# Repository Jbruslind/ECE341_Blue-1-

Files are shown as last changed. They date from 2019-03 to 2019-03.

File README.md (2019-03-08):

# ECE341 Final Project - AC Bluetooth Switch
Final project for ECE 341 (Junior Design II). Made by Jorian Bruslind, Mack Hall, and Zach Bendt. 
This project uses an ESP32 microcontroller to facilitate all the necessary functions: Relay control, 
sensor measurement, relay control, and bluetooth/wifi connections. 
#	Requirements for project

##	Base Engineering requirements
The project's base requirements, standard for all bluetooth switch teams

1. The system will turn off and on at least 2 independent household lamps with up to 100W incandescent 
bulbs and report current watts delivered by each channel.
2. 9 out of 10 users will be able to turn the switches off and on from a mobile phone in less 
than 10 seconds without any training or having previously seen the interface.
3. The system will use only US standard plugins for connecting to external devices and will not 
allow any object with a diameter greater than 1mm to enter the enclosure, and will be disable if 
more than 5A is drawn from the wall power.
4. The system must turn off the output after a time of up to 1 hour ± 1 minute when enabled.
5. The system will be able to accept commands from a mobile phone over 20 feet away from the plug-ins.

##	Specialized requirements
The project also allowed for teams to specify their own 2 unique requirements

1. The system will have WiFi capabilities 10m or more away from a standard household router and 
will have a web interface that is accessible from a laptop/browser. 
2. The system must be able to accept voice commands through a mobile phone using the Google Now 
API for all functionality. 

# System Overview
The overall project was broken up into many different "blocks" that could be individually assigned
and constructed. 

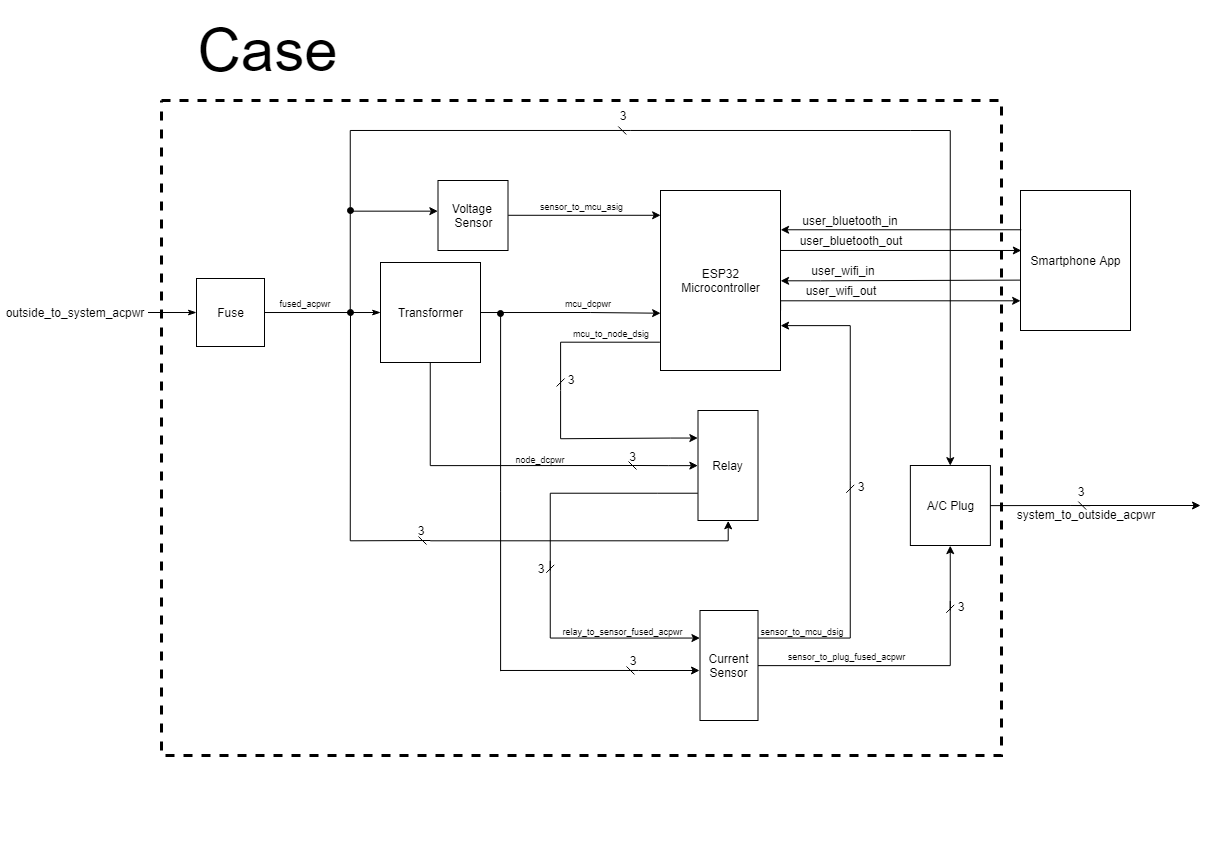
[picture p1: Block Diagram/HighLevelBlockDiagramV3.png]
Block Diagram connections


1. Fuse - Find a fuse (or circuit equivalent) that is able to break only at 5A within ~.5sec. 
This should be resettable and can be inserted easily into a PCB

2. Transformer - This block is supposed to take in 120Vac (US mains power) and convert it
down to 5V at ~2A. 

3. Voltage Sensor - This block will measure 120Vac and output some measurable signal. 
This could be a radiometric voltage (0-5V) or through some serial protocol.

4. Relay - This block should be a electrically controlled switch (a relay), that can 
take in some voltage signal from 0 - 5V and switch a voltage line which will be 120Vac @ 0 - 5A

5. Current Sensor - This block will take in the individual 120Vac lines (3 total)
and output a signal that corresponds to the current flowing through said lines. This
signal can be radiometric or serial.

6. AC plug - This block will output the shared 120Vac line (after it goes through each relay)
and have accessible ports to 120Vac (line), 0V (neutral), and earth ground. 

7. Smartphone app - This will be a piece of software that can be run on a typical
android OS version (4.0+) and can interface with the ESP32 controller. It must be
"user friendly" in that someone with no exposure to the device prior will be able
to navigate it. This must also use the Google Now API for voice activation/control

8. Wifi Control (not pictured) - This must be some piece of software that allows
for control of the ESP32 microcontroller through a "user friendly" interface. There
are little restrictions to how this can be done other than it must use Wifi and be 
easy to navigate. 

# More info

Each directory has a small readme file that explains what aspect it served in the project
as well as more information about how the project was done. (Example: PCB production files
contain info about the PCB)

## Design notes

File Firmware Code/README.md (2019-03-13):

# Firmware Code

This folder holds all of the code used throughout this project. This code is primarily used for 
controlling the microcontroller used on the custom PCB, the ESP32. The code was done in C++ via 
the Arduino IDE. Within the folder, there also exists the flow diagram for the NodeRed server 
that handles the user web interface.

Individual pieces of code are present in this folder, which was how they were developed. After the
individual pieces of code were able to successfully work on their own, they were adapted into a
single .ino file to be uploaded to the ESP32, called ESP_Firmware.

##	Functions

###	void check_time()
Helper function whose main job is to check the timers and current time. When the current time 
minus the time each timer started goes beyond the set time limit, it calls a separate function 
to turn off the plugs and reset all the values. 

This could be improved by consolidating the functions (a previous revision needed 3 seperate functions
this current revision does not) so only one "timer complete" function is called with a specific argument 
for what plug to turn off (Ex. Timer_complete(1) -> turn off plug one). 

Inputs: None

Outputs: none

### String get_time(int time_to, int plug)

Helper function that will convert the time data variables (which are stored as raw millisecond values) to
human-readable strings. In this case it will take in the time at which the plug timer started (time_to) and
how long the plug is supposed to remain on (plug). These values are used along with the current time (millis)
to find exactly how long it's been since the plug timer started. This value is then divided into hours, minutes
and seconds and then casted into a string with the format HH:MM:SS. 

This function is kinda clunky because it uses strings and not char arrays. Since the format is known (HH:MM:SS) 
it would be better to just have a 8 char static array and then populate it with values as we calculate them. 

Inputs: Time that the timer started at (time_to), how long the timer is on for (plug)

Outputs: String formatted as HH:MM:SS (int values)

### void timer_complete_X()

There are 3 of these functions for each plug. All it does is turn "off" the plug (by setting the relay high) and
resets the time the plug is supposed to be on to 0. 

This is kind of a stupid way to do this and it should definitely be improved. Consolidating it into another function
and not having 3 seperate functions to do a very simple task would be a good start. 

Inputs: None

Outputs: None

###	setup_wifi()

This function will attempt to connect to the specified wifi SSID with the given password. IT is a blocking function 
and will hold up all other operations if it cannot connect to the givien SSID. 

This should be fixed so that it is not blocking and will just retry the connection every X seconds when it can't connect.

Inputs: None

Outputs: None

###	 start_timers()

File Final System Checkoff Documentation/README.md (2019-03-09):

# Final System Checkoff Documentation

This folder holds all of the artifacts used to demonstrate to our client, Westley Wurscher, that our system has met all of the engineeering requirements that we had agreed upon. All of the PDFs are artifacts showing a rough idea of how our system works, including a block diagram, interface definitions, a BOM, and more. 

There is also a folder called "Videos", which has (you guessed it) videos that show our system working as intended. We have a video to show that our timer is capable of reaching 60 minutes and capable of keeping time, a video showing that our system turns off once our timer is finished, a video showing that the system is controllable via bluetooth smartphone app, a video showing that our system is controllable through a WiFi interface, and, finally, a video showing that our system is controllable via a voice command input.

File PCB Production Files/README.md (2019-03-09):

# PCB Production Files

This directory holds all the necessary information/files to manufacture the project
PCB. The manufacturing files directory holds all the gerber files (7 layers: Top Copper Layer, 
Top Silkscreen Overlay, Top Soldermask Layer, Bottom Copper Layer, Bottom Silkscreen 
Overlay, Bottom Soldermask Layer, and the Keepout Layer which serves as the board outline).
This directory also holes the drill files (Slotted holes and round holes)

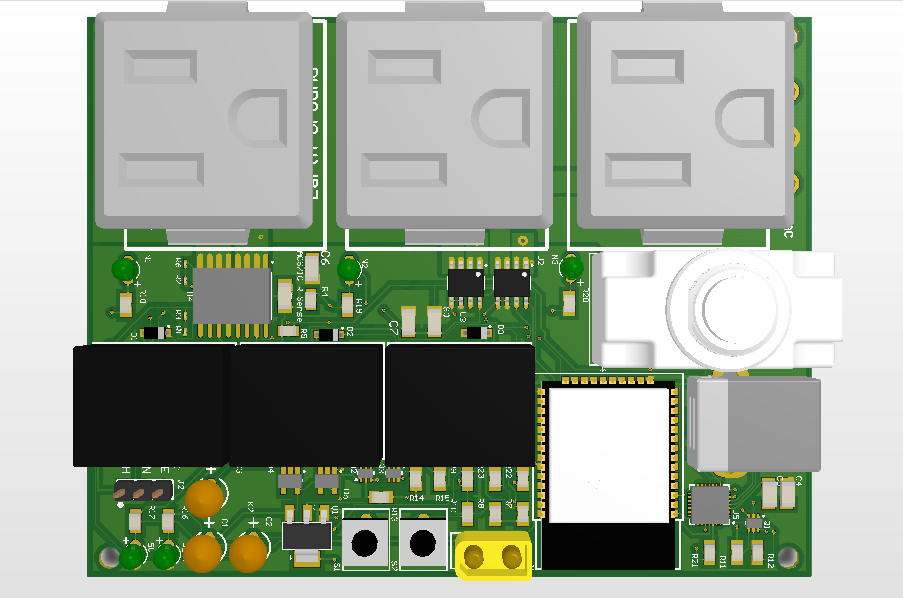
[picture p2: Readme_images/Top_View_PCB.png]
Render of board


The gerber files directory contains all the above files as well as all the other layers
that are not used in production (usually just used for reference inside CircuitMaker). This
includes some layers which we used to designate spacings between objects and layers used
to create unqiue shapes of copper pours. 

The Bluetooth Switch directory holds all specific information about the project which
include pdf versions of all schematics and the PCB print, as well as other useful files 
such as a Bill of Materials and STEP file output of the whole board. 

## Special Layout Considerations

There weren't very many layout considerations that had to be made for this project. 
Other than trace sizes and component placement, the only special considerations that had
to be made involved the placement of the I2C signal lines, placement of the UART D+ and D-
lines from the UART-TTL bridge and the spacings between the AC voltage lines and the DC 
signal/power lines. The PCB was grouped into various segments to simplify component placement.
For example, the ESP32 segment included the ESP32, USB programmer, UART Bridge, EN/Boot
transistor and peripheral capacitors/resistors. This was grouped this way so all the 
important connections would be close together for easy routing. Other groupings
included the relay nodes (which included the relays, current sensors, flyback diodes, 
status LEDs, output plugs, and peripheral resistors/capacitors) and the power supply
which included the ORing diodes, input filtering capacitors, and Linear Dropout Regulator. 

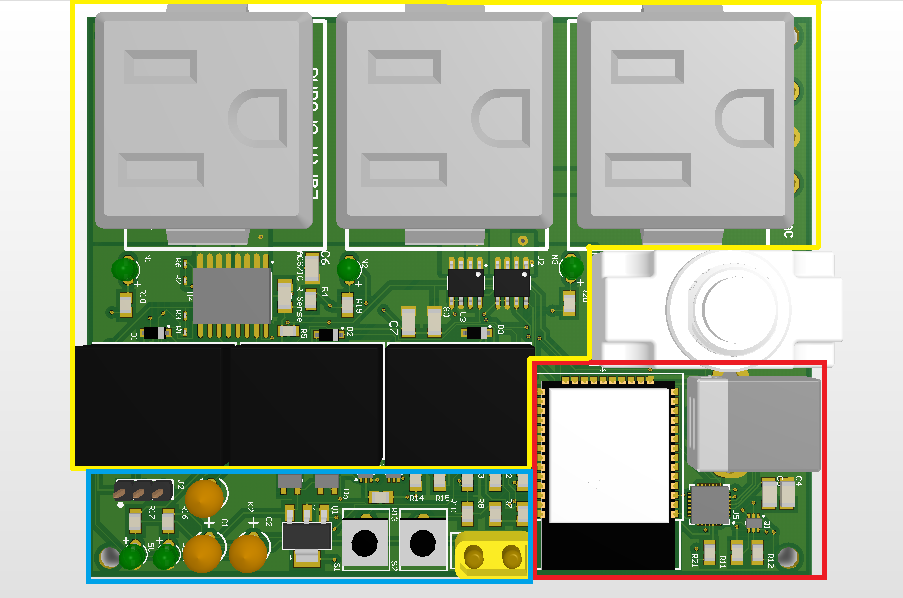
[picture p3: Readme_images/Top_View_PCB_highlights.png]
Highlighted Sections


1. Red indicates the ESP32 section
2. Blue indicates the Power section
3. Yellow indicates the Relay Node section

### Connectors
For this project, a USB B connection was chosen to act as our USB interface as it is 
robust and very durable. Initially the project used a USB micro due to its abundance
in other products, but this was found to be easily broken and torn out of the board. 

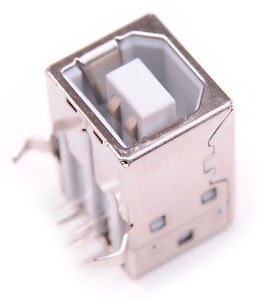
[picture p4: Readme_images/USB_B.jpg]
USB B Connector


The power outlets were chosen to be NEMA standard C13 plugs so that way we would only 
need to solder the plugs into the board (no wires). Unfortunatly most of these plugs
were panel mount, meaning it was not easy to plug into a PCB, but we were able to find 
PCB mount plugs (which were adapted panel mount plugs) on Digikey [here](https://www.digikey.com/product-detail/en/qualtek/739W-X2-32-A/Q1211-ND/8681866)

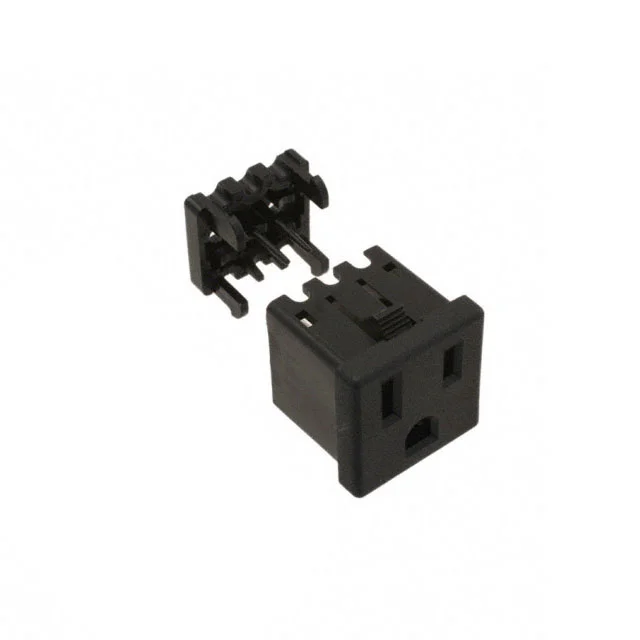
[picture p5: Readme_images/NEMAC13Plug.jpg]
C13 Plug made by Qualtek


The input DC power was chosen to be an XT30 plug which is a 2 pin, yellow, friction fit 
plug that is often used on drones/quadcopters for lithium batteries. DC power only needed
to provide .5A and the XT30 is rated for 30A per plug.  

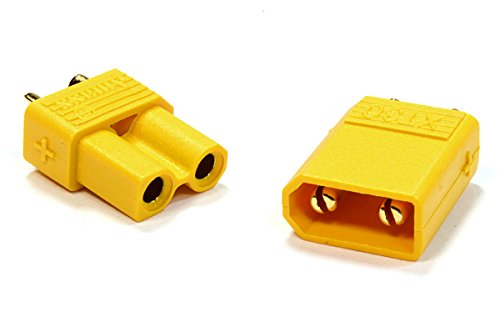
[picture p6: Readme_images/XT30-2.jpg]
XT30 Connectors


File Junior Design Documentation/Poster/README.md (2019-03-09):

# Poster

This project was for ECE 341/2 at Oregon State University. At the end of the second term, teams would show off their projects at a Junior Design Expo. This was the poster used to show off this project on 3/14/19 by Bluetooth Switch group 1.

This folder contains all of the artifacts and pictures used to decorate the poster. These include mechanical drawings of the case, a rendering of the populated PCB, a block diagram of the entire system, a graph showcasing the sampling technique used to calculate RMS values, and a picture of the user interface for both the smartphone app and web interface respectively.

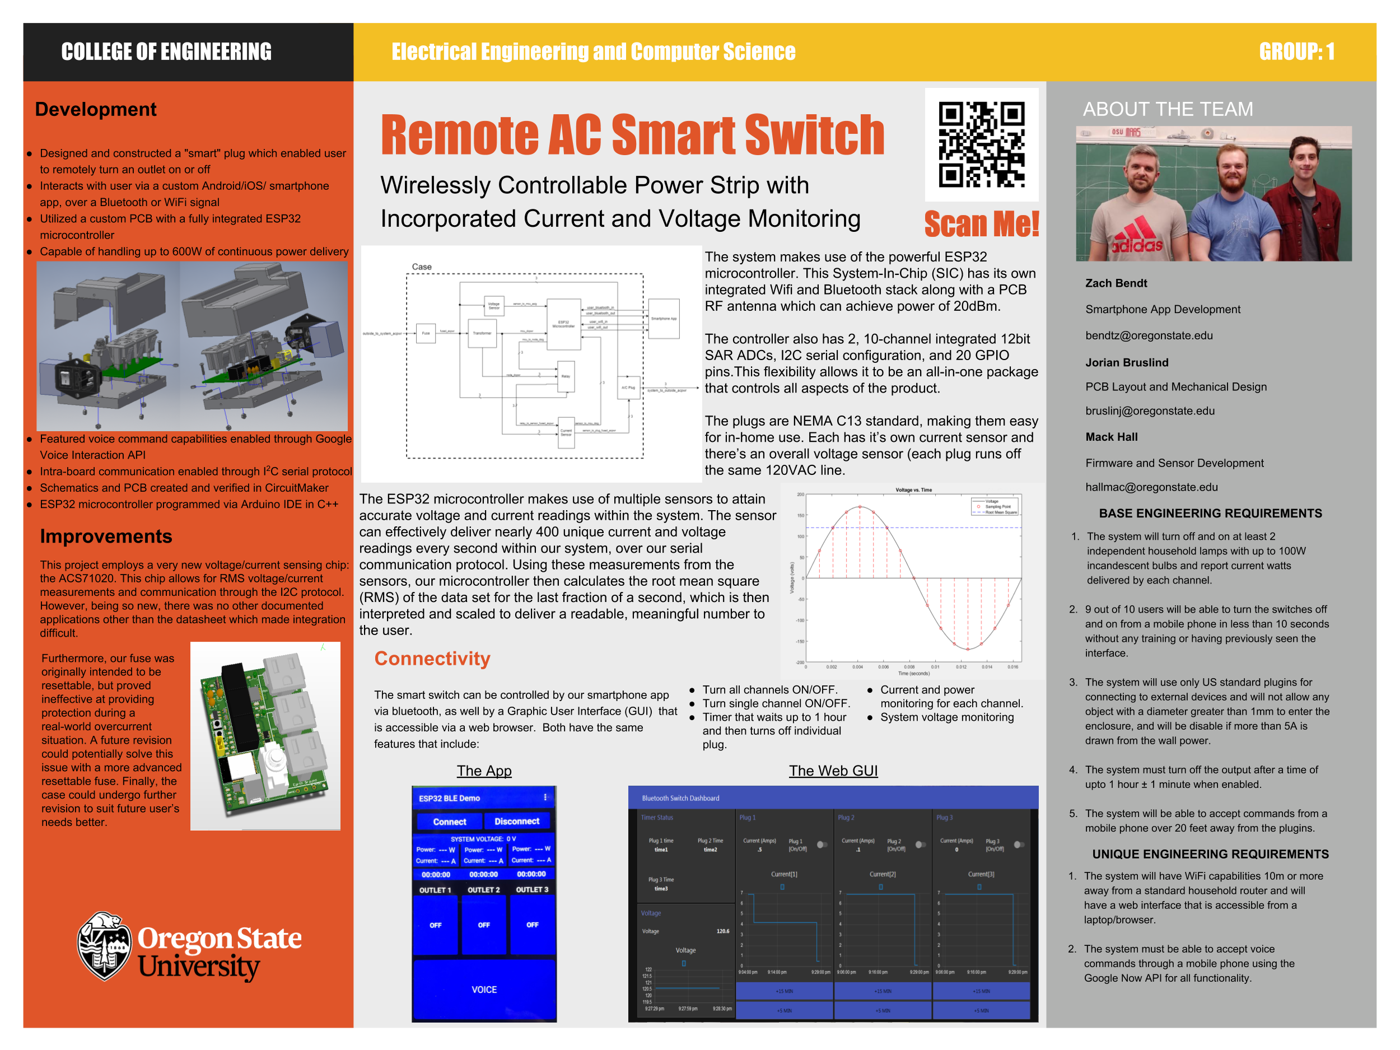
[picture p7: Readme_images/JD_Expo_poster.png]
Poster


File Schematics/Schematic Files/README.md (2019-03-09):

#	Schematic files
This folder contains all the schematic files as pdfs for easy viewing. The project
was designed using the Altium Circuitmaker software. All project files are open 
for anyone to use and can be found in the project search engine within Circuitmaker. 
##	MCU
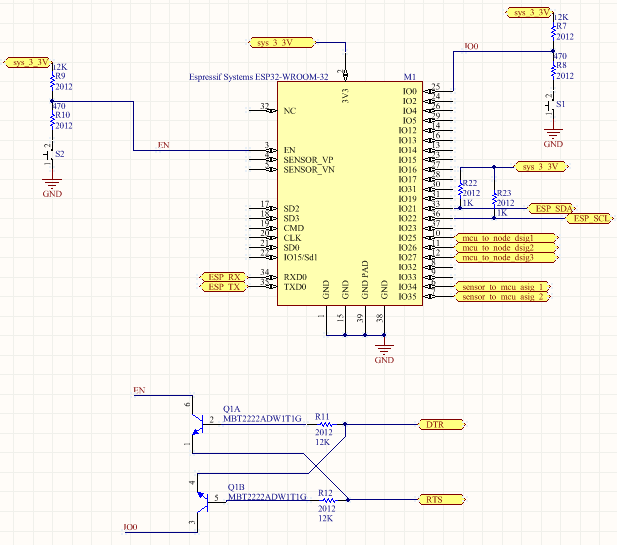
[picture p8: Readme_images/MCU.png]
MCU


This is the ESP32 general connection page which provides ports to the other 
necessary sheets within the project. The ESP needs a 3.3V VDD and all its pins
are 3.3V tolerant (not 5V). The inputs are for the I2C bus, 2 radiometric current sensors, 
3 relay control lines, UART programming, and for power/gnd.

The BJTs are used for programming the ESP over USB (seen below in the UART->TTL bridge).
The switches on EN and IO0 are used for programming and resetting respectively.

##	UART Bridge
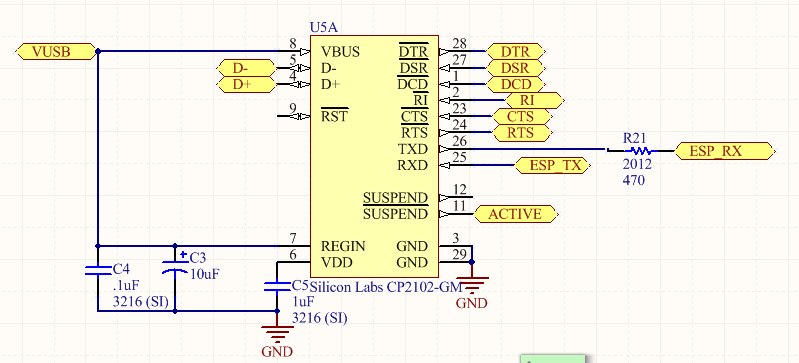
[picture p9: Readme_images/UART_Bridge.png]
UART Bridge

 
 The ESP32 does not have a native way to communicate over UART (USB signals), so a UART-TTL bridge
 was chosen to perform that job. The Silabs CP2012 is a popular choice among other microcontroller
 development boards and has a proven design. This chip will take in the USB signals from some external
 controller and program the ESP32. 
 
 ##	3.3V LDO
 
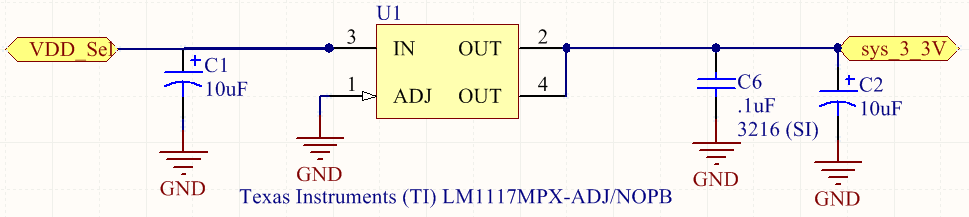
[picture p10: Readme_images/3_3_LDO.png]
3.3V LDO
 
 
 The input voltage that we are using for this board is expected to be 4.5 - 5.5V. The ESP32 and 
 the other peripheral sensors cannot tolerate this voltage normally. So a Low Dropout Regulator
 was chosen to step this 5V voltage down to 3.3V. This was chosen to be the LM1117 which is, again,
 a popular choice among development boards for 3.3V supplies. The necessary current was calculated
 to be ~.5A for all the board components (.3A alone for the relays). The LM1117 can supply up to .8A
 at max, which was more then enough for our application. 
 
 ##	Input Plugs
 
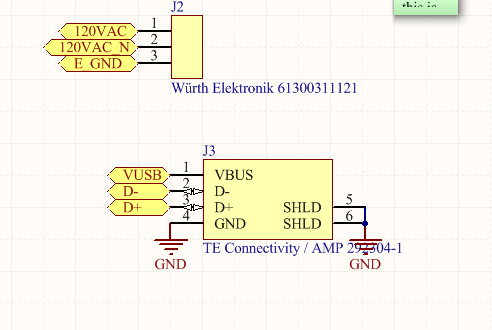
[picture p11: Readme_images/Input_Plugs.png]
Input Plugs
 
 
 This schematic is just the input USB port (for programming/power of the ESP32 and sensors)
 as well as testing pins for the 120Vac (line, neutral, and Egnd). 
 
 ## Current Sensor ACS722
 
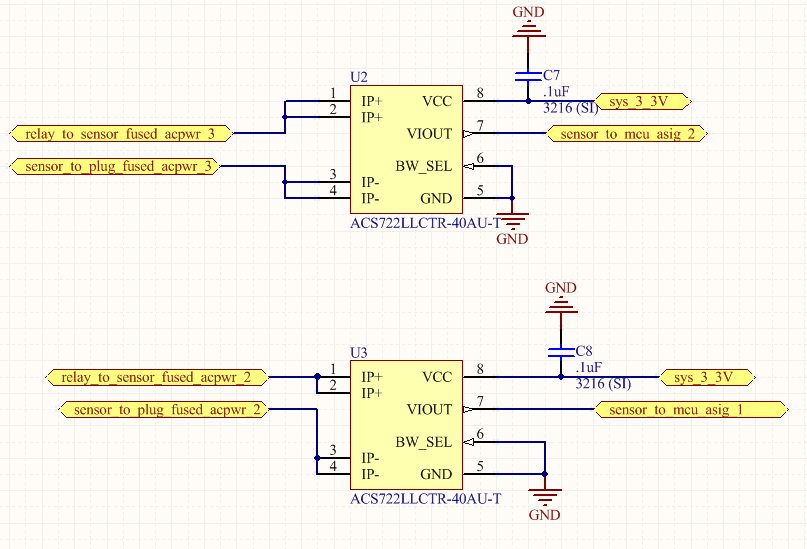
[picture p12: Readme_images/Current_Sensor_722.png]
ACS722 Current Sensor
 
 
 The ACS722 is a very powerful current measuring chip that uses the Allegro Hall effect technology. This 
 chip is able to measure up to +-10A of current and output the result as a radiometric voltage signal
from 1.5V -> 0A to 3.3V -> 10A. This is a linear relationship and has a sensitivity of ~267mV/A. 
Using the ESP32's built in Analog - Digital Converters (ADCs) we are able to measure this signal 
with an accuracy of 12 bits over 3.3V (as in 0000.... = 0V and 1111.... = 3.3V) with a resolution
of 2^12 / 3.3V (or ~.8mV). This translates to a  .8mV/bit * 1/267 A/mV = .003 A/bit or 3mA resolution.

## ACS71020 

ACS71020 Current/Voltage Sensor

This chip is actually a very powerful current/voltage sensor for AC applications. Not only is it able to tolerate 120Vac up to
30A, it can also preform RMS, power, actual power, and instantaneous power. The package is also isolated
for voltages up to 1047Vrms in basic isolation and 517Vrms in reinforced isolation. The measurement values
are read over the I2C bus, making communication easy and space efficient. 

*note*: we actually had a very difficult time getting this part to work as the chip itself is very new
(released around Nov '18) and no examples for implementation were found online. So we had to make our 
own I2C drivers for this, which proved difficult as we were inexperienced. 

## Relay Node

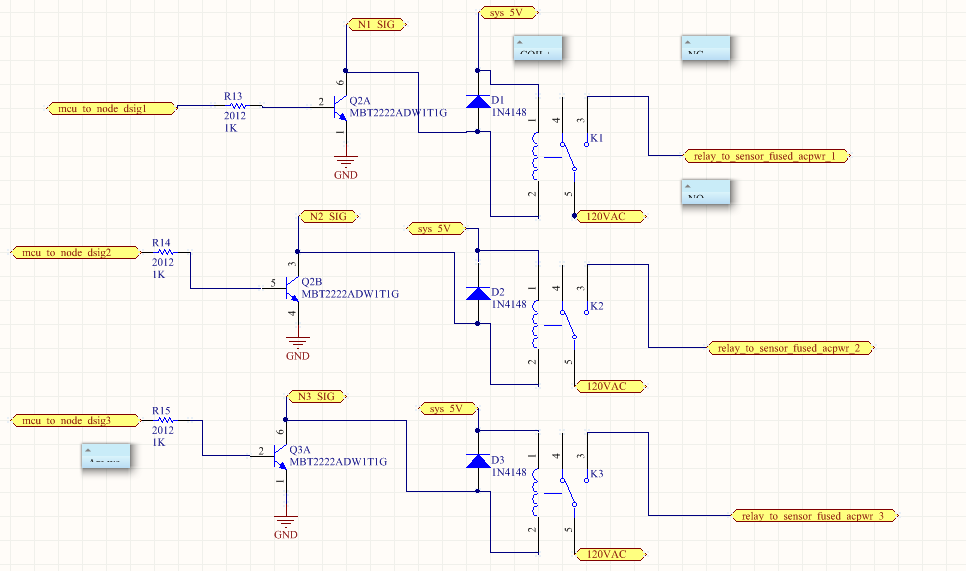
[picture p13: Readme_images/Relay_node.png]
Relay Node


For this the relays are simply electromechanical with a rated usage of ~100,000 switches. They are 
5V compatible and take ~70.2mA for full activation/saturation. In this circuit the ESP will send a 
3.3V signal to a 2N222 bjt amplifier (with ~100 gain, this equates to ~.7mA from the ESP) which in
turn will supply the necessary current for the relays. Each one has an LED line attached to it so that
there will be a status LED which will light up when active (when the ESP sends a +3.3V signal). As of 
the writing of this, the relays were connected wrong in that the output line was connected to the 
"Normally Closed" (NC) pin of the relay (meaning when ESP sends 3.3V it will be open, and normally closed)
This should be changed to the "Normally Open" pin. 

## Voltage Selection Diodes

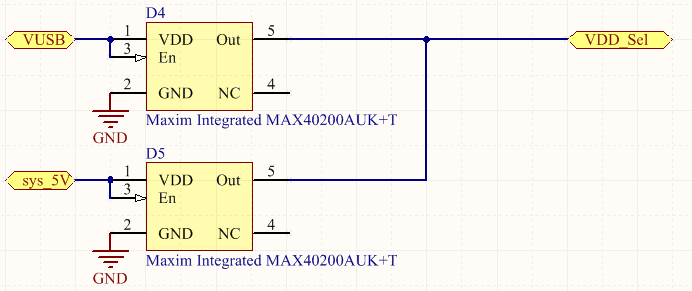
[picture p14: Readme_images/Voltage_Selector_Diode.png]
Voltage Select


There will be situations where we would like to only power the ESP32/peripheral sensors (to program, test, etc) and *not* 
anything else (since powering the relays might overcurrent a USB 2.0 port on say a laptop. As such it would be good to have 
a USB voltage input and a normal 5V input. Having 2 separate voltages however can cause issues (if they are trying to 
backdrive each other). A solution was made where we would use 2 Oring diodes that will only let the higher of the 2 
voltages act as the driving voltage, while still allowing the other to be connected. This lets us power only the 
ESP32/periphery using the USB voltage (to program) and still being able to plug in the 5V line later on if we want to 
do testing. We can also power the whole board from the main 5V while using the USB connection 
to do debugging.

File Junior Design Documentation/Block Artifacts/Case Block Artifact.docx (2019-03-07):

Jorian Bruslind

2/7/19

ECE 342 - Blue 1 | AC Bluetooth Switch

Prof. Shuman

Interface & Property Definition Table for AC Bluetooth Switch Case

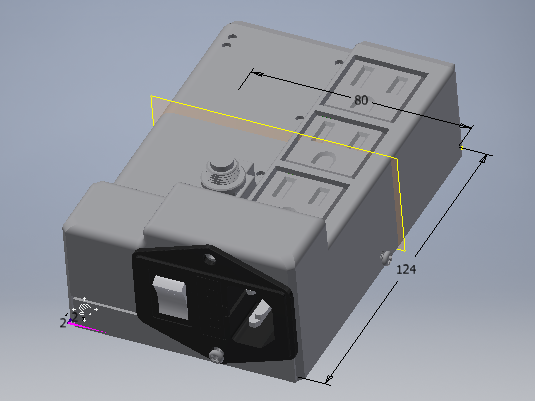
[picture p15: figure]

Fig. 1. Render of Case

This is our enclosure for our AC Bluetooth switch. It is fully 3D printed using PLA plastic, which will have a total print time of roughly 12 hours. The goal for this case was to ‘ruggedly’ enclose the system, which has been specified as not allowing anything bigger than a pencil be able to pass through. Furthermore, all wire connections to the PCB going through the enclosure (entering or leaving) must use connectors.

The case exposes a NEMA-15R compliant input plug to receive power from the wall, a physical on/off switch, and three output channels to plug NEMA-15R components into that you wish to power. Every other component of the project is enclosed by the 124mm x 80mm x 50mm case. The custom PCB is held on four standoffs, while the top of the case is mated to the bottom via four M3 screws.

Table 1. Interface Definitions

outside_to_system_acpwr | NEMA-15R compliant VNominal: 120VACRMS VMin: 0V Physical cutoff switch
system_to_outside_acpwr | NEMA-15R compliant VNominal: 120VACRMS * 3 channels VMin: 0V * 3 channels


Fig. 2. High Level Block Diagram of System

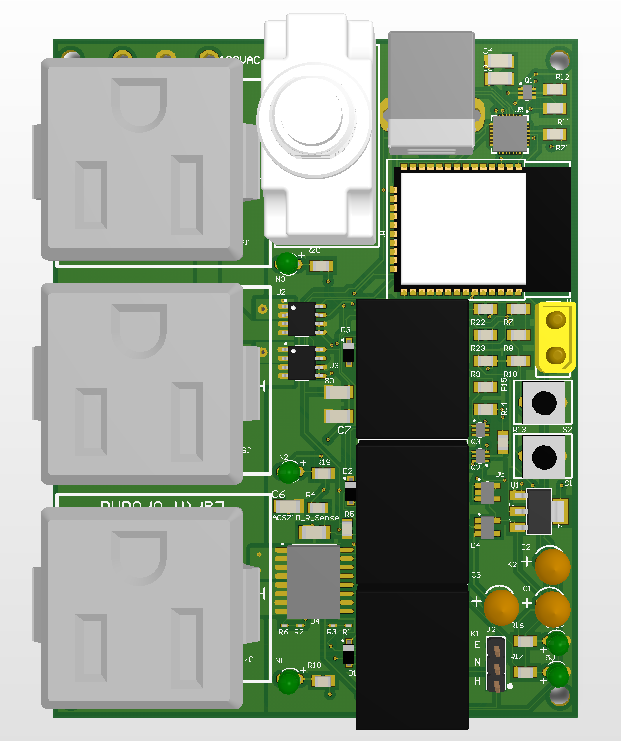
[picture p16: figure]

Fig. 3. Render of the PCB to be enclosed

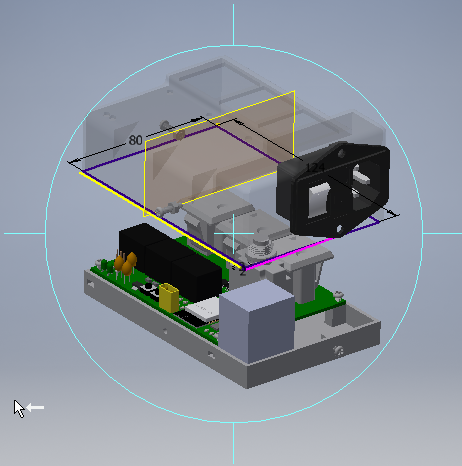
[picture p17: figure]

Fig. 4. Isometric Exploded View of the Case

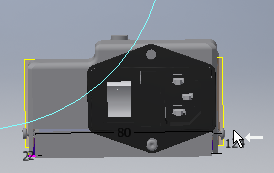
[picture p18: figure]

Fig. 5. Side View of the Case

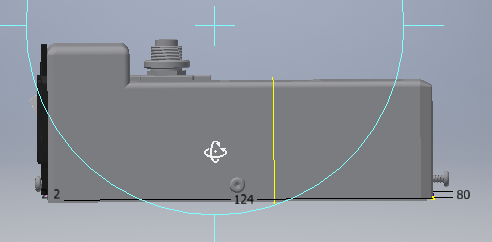
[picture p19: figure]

Fig. 6. Rotated Side View of the Case

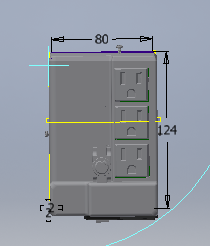
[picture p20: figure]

Fig. 7. Top View of the Case

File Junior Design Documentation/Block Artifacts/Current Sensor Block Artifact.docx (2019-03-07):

Mack Hall

2/7/19

ECE 342 - Blue 1 | AC Bluetooth Switch

Prof. Shuman

Interface & Property Definition Table for ACS722LLCTR-40AU-1 Current Sensor

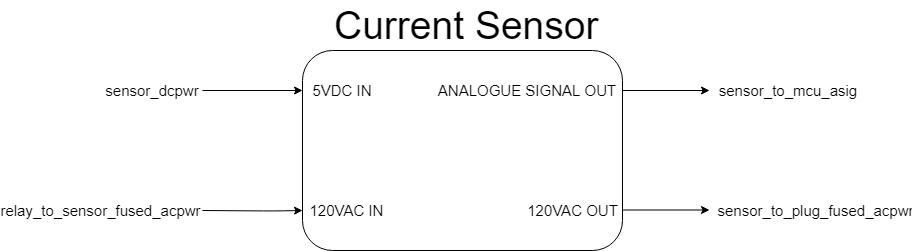
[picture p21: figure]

Fig. 1. Black Box Diagram of Current Sensor Block

Table 1. Current Sensor Block Interfaces and Properties

Interface | Properties
sensor_dcpwr | VMin: 3VDC VNominal: 3.3VDC: VMax: 3.6VDC INominal: 9mA IMax: 12mA
sensor_to_mcu_asig | VMax: 6 VDC VNominalLow: 0.36 VDC VNominalHigh: 5 VDC VMin: -0.5 VDC tRise: 4㎲ tResponse : 5㎲ tProp: 1㎲
relay_to_sensor_fused_acpwr | VNominal: 120VACRMS IMax: 5A IMin: -5A fNominal: 60Hz
sensor_to_plug_fused_acpwr | VNominal: 120VACRMS IMin: -5A IMax: 5A fNominal: 60Hz

Fig. 2. High Level Block Diagram of AC Bluetooth Switch


Fig. 3. Schematic for Current Sensor Connections

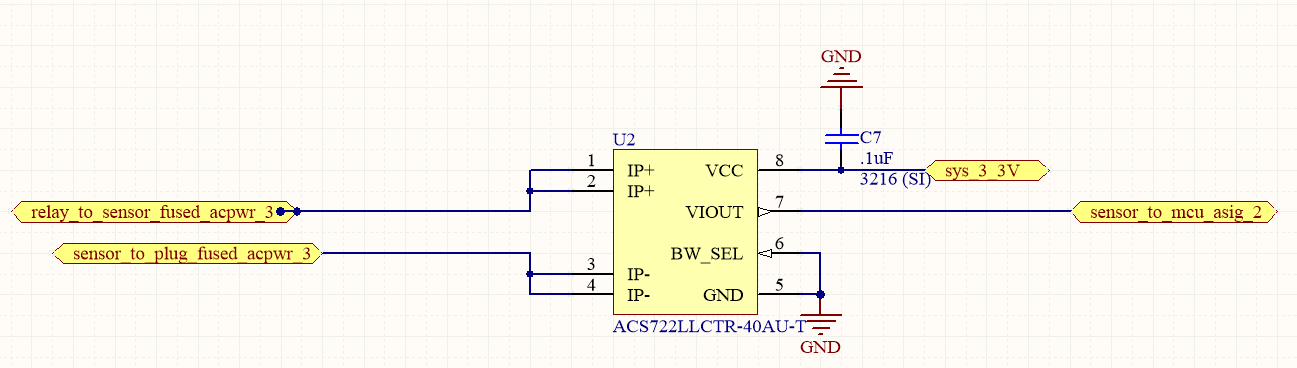
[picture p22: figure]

Fig. 4. A Render of the PCB

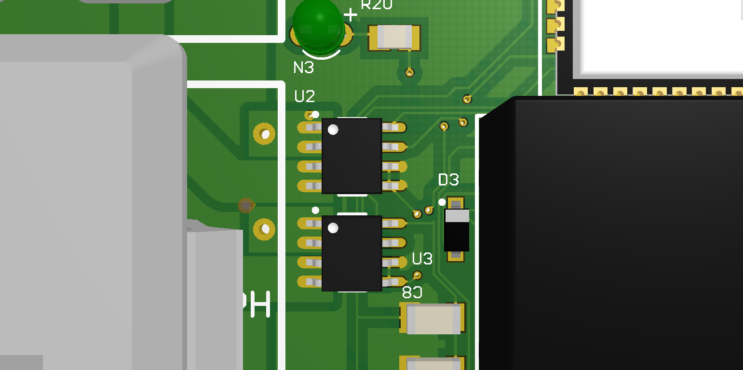
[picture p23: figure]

Fig. 5. Closeup of Current Sensor on PCB

Test Cases:

Nominal Current:

1. Connect the GND pin and the bit select pin to ground.
2. Apply 3.3 VDC to the VCC pin.
3. Connect the VIOUT pin to an ADC pin of a microcontoller. Take note of the reading it reports when there is no load attached. This is the zero-load bias we need to account for when taking later measurements.
4. Apply a load of 5A to the IP+ and IP- pins of the IC.
5. Subtract the zero-load bias we found earlier from the reported value. Afterwards, scale the result by the amount specified in the datasheet.

PASS: 5A +- 2% is being reported.

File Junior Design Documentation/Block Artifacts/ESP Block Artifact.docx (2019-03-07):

Mack Hall

1/25/19

ECE 342 - Blue 1 | AC Bluetooth Switch

Prof. Shuman

Interface & Property Definition Table

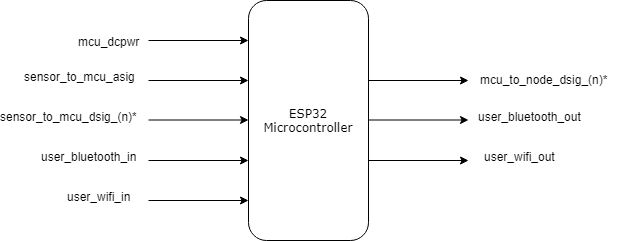
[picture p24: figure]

Fig. 1. Black Box Diagram of ESP32 Microcontroller Block

Table 1. ESP32 Microcontroller Block Interfaces and Properties

Interface | Properties
mcu_dcpwr | VNominal: 3.3VDC: VMax: 3.6VDC VMin: 2.3VDC IMin: 500 mA
sensor_to_mcu_asig | VMax: 6 VDC VNominalLow: 0.36 VDC VNominalHigh: 5 VDC VMin: -0.5 VDC
sensor_to_mcu_dsig_(n)* | VHighMin: 0.75*mcu_dcpwr VDC VHighMax: VDD + 0.3 VDC VLowMin: -0.3 VDC VLowMax: 0.25*mcu_dcpwr VDC
user_bluetooth_in | Must be able to enable/disable relays Must be able to set a time up to 60 min. Must be able to give commands from over 20 ft Interface must be via a mobile phone (Android)
user_wifi_in | Must be able to enable/disable relays Must be able to set a time up to 60 min. Must be able to give commands from over 20 ft Interface must be via a mobile phone (Android)
mcu_to_node_dsig_(n)* | Disables output after 1 hr. if timer enabled Operates output channels independently IMax: 1.2A IMin: 0A
user_bluetooth_out | Must be able to report on current/voltage draw Must be able to report data to phone 20 ft away Must be able to confirm length of timers Must be able to disable channels if timer is up
user_wifi_out | Must be able to report on current/voltage draw Must be able to report data to phone 20 ft away Must be able to confirm length of timers Must be able to disable channels if timer is up

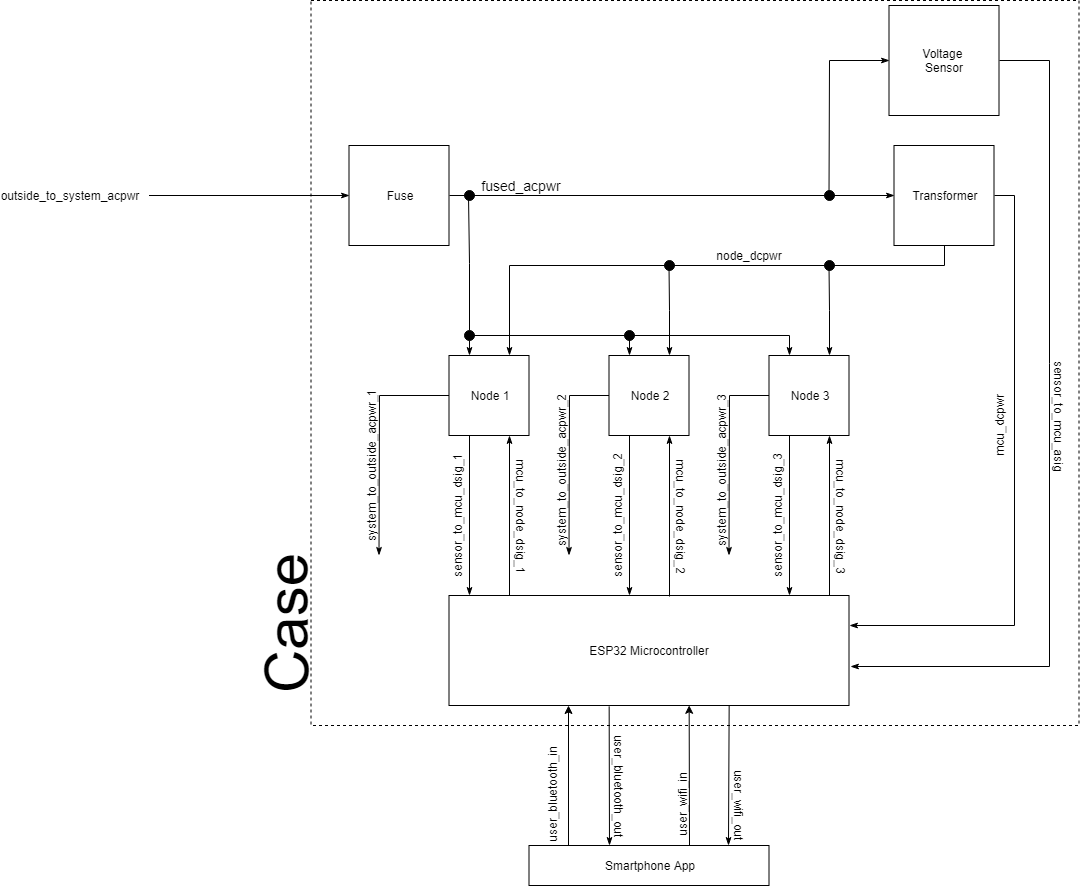
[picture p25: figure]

Fig. 2. High Level Box Diagram of AC Bluetooth Switch


Fig. 3. Schematic of ESP32 Microcontroller Block in Custom PCB

Fig. 4. Schematic of Custom PCBFig. 5. Closeup of Schematic of ESP32 Microcontroller Slot on Custom PCB


NOTE: The KEEPOUT section has no traces running through it, as to avoid interference with the bluetooth and WiFi signals the microcontroller is sending and receiving.

Fig. 6. Custom Code written to the ESP32 Microcontroller

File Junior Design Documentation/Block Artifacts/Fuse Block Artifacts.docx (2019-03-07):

Zachary Bendt

January 17, 2019

Remote A/C Switch

Team Blue(1)

Fuse Block Artifacts

Interface | Properties
outside_to_sytem_acpwr | - Vnominal: 120VAC via a NEMA 5-15R connector - Ipeak: 15A - Inominal: 500mA
fused_acpwr | - Vnominal: 120VAC via a NEMA 5-15R connector - Ipeak: 4.5A - Inominal: 500mA - Disconnects system from input when 5A draw is exceeded

Testing

It is assumed that peak current, nominal voltage and current are within requirements as they are supplied by wall outlet.

Steps

A. Disconnects system from input when 3A draw is exceeded

The block should disconnect from the system when the 4.5A limit is reached in order to protect the system from overcurrent. This will test if the fuse is functioning property.

1. Connect the Fuse to a power supply via the outside_to_sytem_acpwr interface at 5V.

2. Connect the Fuse to the DC load at the fused_acpwr interface.

3. Starting with a 100 mA load, slowly increase the load until the 4.5A limit is exceeded.

PASS: Disconnects system from input when 4.5A draw is exceeded.

If the block passes all of the listed tests, all interface properties have been verified and the block is ready for inclusion into the system.

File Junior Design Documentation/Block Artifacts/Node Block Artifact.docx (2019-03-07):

Node

node_dc_pwr

mcu_to_node_dsig

fused_acpwr

sensor_to_node_asig

system_to_outside_acpwr

Interface | Properties
node_dc_pwr | INominal : 261mA Imax : 296mA Vmax : 5.5V Vmin : 4.5V
fused_acpwr | INominal : 0 - 3A (depends on what’s plugged in) Imax : 5A Vmax : 125VAC Vmin : 115VAC
sensor_to_node_asig | INominal : <1mA Imax : <1mA Vmax : 3.3V Vmin : 0V
system_to_outside_acpwr | INominal : 0 - 3A (depends on what’s plugged in) Imax : 5A Vmax : 125VAC Vmin : 115VAC
mcu_to_node_dsig | INominal : 9mA Imax : 10mA Vmax : 3.3V Vmin : 0V

Testing Plan

This block has the relay and current sensor functions built into one. It must be able to switch 120VAC (fused_acpwr to system_to_outside_acpwr) over 0 - 5A using a standard 3.3V (mcu_to_node_dsig) signal from the ESP32. This block will also send information about the magnitude of current being passed to the system_to_outside_acpwr net through a standard 3.3V signal line (sensor_to_node_asig).

Relay Functionality

1. Start with everything powered off/de-energized.
2. Apply 5V to the node_dc_pwr line
3. Apply 3.3V to the mcu_to_node_dsig line
4. Visually confirm the status LED is active
5. Audibly confirm the relay is active (listen for the switch)
6. Using a multimeter in continuity mode, check that the relay terminals from NO to COM are connected.
7. Using a multimeter in ammeter mode, check the current flowing from mcu_to_node_dsig is less than 10mA
8. Repeat steps 3 - 7 for all other relays (if more than 1)

AC Power Functionality

1. Apply Relay Functionality steps 1 - 3
2. Using 120VAC standard household power lines, apply to fused_acpwr
3. While relay is active, measure voltage on COM (fused_acpwr) and NO (system_to_outside_acpwr) relay pins to confirm 120VAC (and that the relay is active)
4. De-energize AC circuit and place a multimeter in ammeter mode in series with the Hot line of the AC power
5. Energize the circuit with AC power
6. Slowly apply a load to the AC power lines until 5A is being drawn
7. Confirm relay is still active after 5A of current

Sensor Functionality

1. Apply Relay Functionality steps 1 - 3
2. Apply AC power steps 5 - 7
3. While ramping up current draw, measure voltage on sensor_to_node_asig and confirm up to 3.3V max (and linear scaling)
4. De-energize circuit and put ammeter in series with sensor_to_node_asig
5. Apply steps 1 - 2 and confirm current draw does not exceed 1mA on sensor_to_node_asig

Node Power functionality

1. Put ammeter in series with node_dc_pwr
2. Apply Relay functionality steps 1 - 3
3. Measure current draw and confirm it is not over 296mA

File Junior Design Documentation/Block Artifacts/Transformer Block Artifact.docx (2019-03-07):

Block 2 Checkoff

Transformer

Transformer Block Introduction

The transformer block includes the transformer which steps down the 120VAC to 5VDC as well as the voltage regulator that converts the 5V to 3.3V. The transformer was salvaged from a Vogek ST270 USB Wall Charger, shown in Figure 1. We removed the USB connectors and connected the transformer to our PCB using an XT30 connector, shown in Figure 4.


Figure 1. Vogek ST270 USB Charger

Block Diagram

Transformer

fused_acpwr

mcu_dcpwr

node_dcpwr (n)

Figure 2. Block diagram for Transformer Block

Interface Definitions

Interface | Properties
fused_acpwr | INominal : 0 - 3A (depends on what’s plugged in) Imax : 5A Vmax : 125VAC Vmin : 115VAC
mcu_dcpwr | INominal : 100mA Imax : 125mA Vmax : 3.3V Vmin : 3V
node_dcpwr | INominal : 261mA Imax : 296mA Vmax : 5.5V Vmin : 4.0V

Schematics

Figure 3. 5V to 3.3V Regulator

Figure 4. XT30 Connection from transformer to PCB

Testing Plan

This block is fairly simple in operation and has the benefit of being a pre-built solution. It must be able to receive 120VAC power (fused_acpwr) and transform that down to 5V nominal @ up to 1.5A (mcu_dcpwr and node_dcpwr).

Power Functionality

1. Begin with everything de-engerized/powered
2. Connect leads to the node_dcpwr and mcu_dcpwr lines and plug them into a programmable dc load
3. Provide 120VAC power to fused_acpwr
4. Measure the voltage output on the DC load side (either with a DMM or the load itself)
5. Ensure the voltage does not go above/below the nominal voltage
6. Activate the load at 0A and slowly increase current draw until 1.5A is being drawn
7. During this time, ensure voltage does not go above/below nominal
8. Leave load at 1.5A for ~10-15min and watch for any voltage discrepancies

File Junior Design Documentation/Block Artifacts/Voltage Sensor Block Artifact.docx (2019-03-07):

Mack Hall

1/18/19

ECE 342 - Blue 1 | AC Bluetooth Switch

Prof. Shuman

Draft Interface & Property Definition Table and Tests


Fig. 1. Black Box Diagram of Voltage Sensor Block

Table 1. Voltage Sensor Block Interfaces and Properties

Interface | Properties
fused_acpwr | VNominal: 120 VACrms: VMax: 120 VACrms INominal: 500mA IMax: 5A fNominal: 60 Hz
sensor_to_mcu_asig | VMax: 6 VDC VNominalLow: 0.36 VDC VNominalHigh: 5 VDC VMin: -0.5 VDC

Testing Steps

A. Nominal Voltage Testing

This block must be capable of measuring the voltage being supplied through the switch to the outlets.

1. Connect the voltage sensor block to the microcontroller block. Ensure that the microcontroller is able to produce an output that is readable by the tester.
2. Connect the voltage sensor block to the fuse block.
3. Connect the fuse block to outside_to_system_acpwr.
4. Probe input for a voltage reading.
5. Record readings from microcontroller.
6. Disconnect fuse block from outside_to_system_acpwr.
7. Repeat steps 1-2.
8. Generate an AC voltage source of 5 VACrms and 30Hz.
9. Connect to voltage sensor block.
10. Repeat steps 4-5.

PASS: This block passes if the microcontroller produces voltage readings between 117.6-122.4 VACrms for the 1st test (wall source) and voltage readings between 4.9-5.1 VACrms for the 2nd test (lab generated signal). The output has a maximum acceptable error of 2% for expected operating temperatures of the block.

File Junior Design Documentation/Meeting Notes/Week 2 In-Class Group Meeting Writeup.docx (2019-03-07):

Present: Mack Hall, Jorian Bruslind, and Zach Bendt

Absent: N/A

ECE 342

1/17/19

Prof. Shuman

Week 2 In-Class Group Meeting Notes

- Each member should be ready for the upcoming block checkoff
  - Has been double-checked with client, due to unique layout of project
    - Client solely requires that the PCB be ordered, while we already have PCBs in hand
      - Our group is very much ahead of schedule
  - PCBs will still be built and tested incrementally in order to ensure functionality
  - The case is the only other ‘block’ that will need to be checked-off in the future
    - Block diagram could potentially need updating to reflect this
      - Interface definitions/properties should not need updating
- Provisional PCB testing is underway
  - A few non-fatal “quirks” have been caught already
    - A few resistor package sizes should be tweaked for easier soldering
    - USB-UART bridge package size may be changed in the future for easier soldering
    - XC60 transformer leads are accidentally switched
    - Relay footprints will be tweaked for easier soldering
    - All quirks are being documented to be mitigated in future board revisions
  - USB-UART bridge is functioning properly, allowing for custom code to be uploaded to microcontroller
  - Once testing is done, another revision of the board will be designed and ordered
    - Next revision also plans to include additional contact info for group members (email, websites, etc.)
      - QR code for documentation also being considered
    - Once board design is finalized, the case design can be finalized as well
  - Fuse testing requires >5A, while Dearborn lab supplies only go up to 3A
    - In contact w/ Dr. Brekken in order to source more powerful supply
    - Could also potentially build a custom current source as well, but don’t want to spend time/money if unnecessary.
- Group meetings plan to continue every Thursday
  - Communication frequency and quickness in Slack and in-person discussions are satisfactory and should be continued
    - Any additional questions/comments/concerns are highly encouraged to be asked through these channels

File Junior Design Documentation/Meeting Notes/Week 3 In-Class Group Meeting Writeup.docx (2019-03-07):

Present: Mack Hall, Jorian Bruslind, and Zach Bendt

Absent: N/A

ECE 342

1/24/19

Prof. Shuman

Week 3 In-Class Group Meeting Notes

- Each member is ready for the upcoming block checkoff
  - 1st revision PCB partially built to show off blocks
    - Shows voltage regulator (5VDC --> 3.3VDC) working via LEDs
    - Shows relays working via LEDs and audible clicking
    - Shows app/microcontroller working via activating relays over bluetooth
  - Will take place at 12:00 on Friday (1/25/19) with Westley
- Provisional PCB testing is complete
  - 2nd revision has been designed and ordered
    - Includes updates to mitigate faults found in 1st board
      - New relay footprint
      - New USB-B connector
      - New shunt footprint for current sensor
      - Corrected XC60 connection polarity
        - Will switch to XC30 in the future for decreased size
      - Ordered stencil
      - Includes additional designer contact info and easter eggs
    - New revision should arrive this Monday (1/28/19)
      - Once arrived, we have everything we need for a working model
    - The case will now begin finalization to accommodate new PCB
    - Block diagram has been updated to reflect up-to-date system
  - App and microcontroller can now talk together successfully
    - Able to enable/disable relays via bluetooth with a custom android app
  - Current 5A fuse has shown to be unreliable
    - Will not stop device from pulling 5A from wall alone
      - Only tripped at 9A after ~15 seconds
        - Wouldn’t trip at 5A even with prolonged exposure
      - Might require lower threshold than 5A for final product
        - Might use in conjunction with current sensors as failsafe
- Group meetings plan to continue every Thursday
  - Communication frequency and quickness in Slack and in-person discussions are satisfactory and should be continued
    - Any additional questions/comments/concerns are highly encouraged to be asked through these channels

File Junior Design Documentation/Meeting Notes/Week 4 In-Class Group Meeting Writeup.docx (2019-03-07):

Present: Mack Hall, Jorian Bruslind, and Zach Bendt

Absent: N/A

ECE 342

1/31/19

Prof. Shuman

Week 4 In-Class Group Meeting Notes

- Each member has completed their project presentation
  - Received solid feedback on the project from our peers
    - Might change fuse type as a result
    - Considering placing an always-on USB socket on the system as well
  - Overall, received very positive feedback on our project
- 2nd PCB revision now has mounted components
  - Now has mounted ESP32, UART-USB bridge, relays, transistors, and LEDS
    - Able to communicate with app (turn relays on/off) fairly consistently
      - Introduced a new bug that disables communication
        - Troubleshooting is underway
      - Discovered new “quirk” of relays in relation to LEDs
        - Previously “on” position discovered to be “off”
  - Newly ordered stencil makes for much easier assembly
  - Next step is to place and calibrate current sensors
    - Still need to determine if magnetic field shielding is needed
      - Also need to determine if mag. field shielding would interfere with incoming/outgoing Bluetooth/WiFi signals
- Group meetings plan to continue every Thursday
  - Communication frequency and quickness in Slack and in-person discussions are satisfactory and should be continued
    - Any additional questions/comments/concerns are highly encouraged to be asked through these channels
- Next steps
  - Try to fix newly introduced app bugs
  - Mount and calibrate current sensors
  - Introducing WiFi capabilities
  - Revising/printing enclosure

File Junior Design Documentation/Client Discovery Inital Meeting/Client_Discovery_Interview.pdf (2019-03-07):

# Client Discovery Interview - AC Bluetooth Switch

Jorian Bruslind

November 2018

## 1 Overview

For our project, our client was Westley Wurscher. Our client did not have any additional requirements outside of the defined project requirements as described on canvas. These requirements included general constraints (that were relevant to all projects) such as the final product using a student designed printed circuit board (PCB), the final product will not contain a breadboard, the final product will be ruggedly enclosed in a container, and finally, any wire connections to the outside of the enclosure will use connectors. In addition we (the team) gave 4 examples of additional engineering requirements that could be included in the final design. These were: Having the system be waterproof up to IP66 rated, the system will have a ”demo” mode which is able to display all capabilities clearly at the push of a button, the system will be able to use Wifi standards and an HTML interface (in addition to Bluetooth), and the system will be voiced activated on android devices through the Google voice api. Of the 4 presented, the client chose the Wifi integration and waterproof options.

## 2 Client questions

There were a few clarifications needed for the final design to be properly constructed. We asked if there were any restrictions on controlling devices or microcontroller. For example, were we limited to the Atmega series of microcontroller found on the Arduino system or could we use a differnt system. The client stated that we were able to use whatever microcontroller we saw fit. We also asked if the ”rugged” enclosure (as decribed above) could be replaced by an epoxy resin around the device/system. The client stated that this would be an acceptable replacement/adjustment. These were the only questions that were asked of the client during the meeting.

## 3 Possible approach

From our dialogue with our client, we have come up with a rudimentary system that would satisfy the client requirements. Our team intends to use the ESP32S

1

Espressif microcontroller to control our system. This microcontroller has built in Wifi/Bluetooth capabilities and is programmable through the Arduino IDE. This would satisfy the requirement for Wifi/Bluetooth connection. We also plan on using an O-ring sealed enclosure to meet the ”rugged” enclosure and the IP66 rated requirements. We will design a PCB using the CircuitMaker software which will satisfy the custom PCB requirement.

2

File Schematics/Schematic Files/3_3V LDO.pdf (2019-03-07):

Numbe; Revi; ion; ADat; She e; 3_3V_Buck.; chDoc; Dra; exa; s Ins; trum; ent; sys_3_3V C1

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
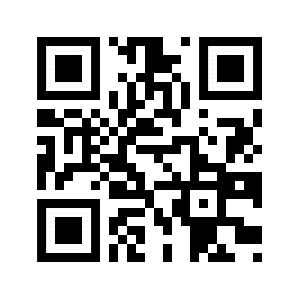
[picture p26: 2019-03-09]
Junior Design Documentation/Poster/Github_QR.png

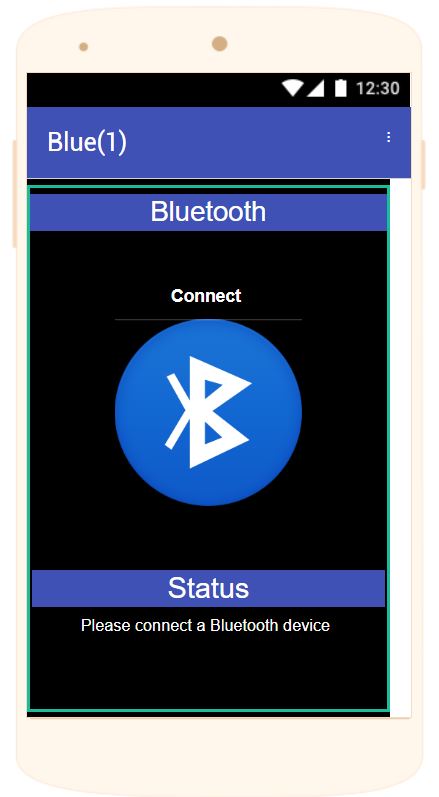
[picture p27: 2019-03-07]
Junior Design Documentation/Poster/App Screen Shot3.JPG

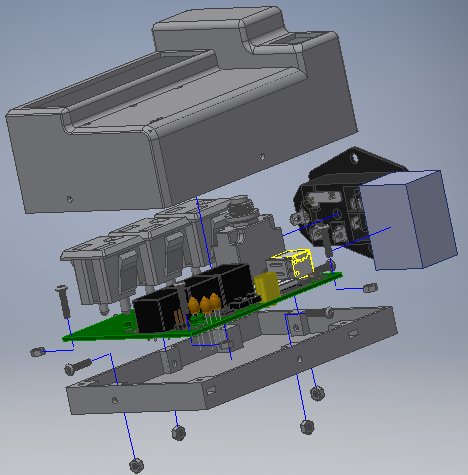
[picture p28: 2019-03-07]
Junior Design Documentation/Poster/Back_Exploded.png

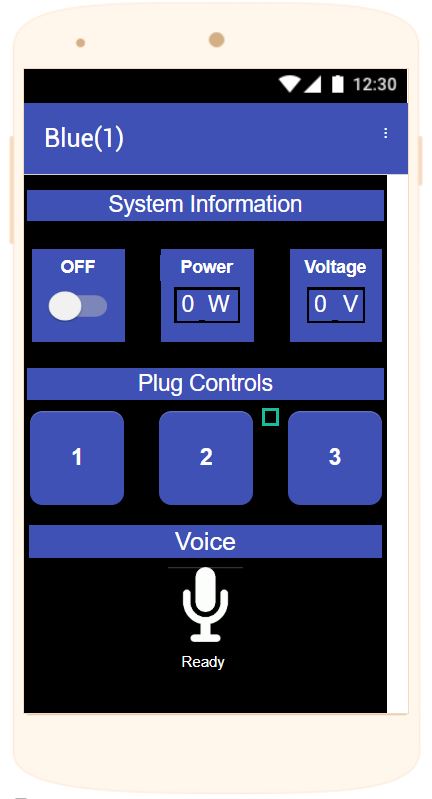
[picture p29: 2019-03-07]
Junior Design Documentation/Poster/App Screen Shot2.JPG

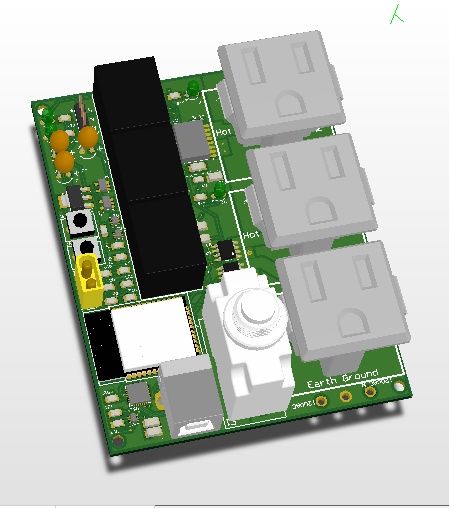
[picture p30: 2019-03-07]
Junior Design Documentation/Poster/BT_Render.png

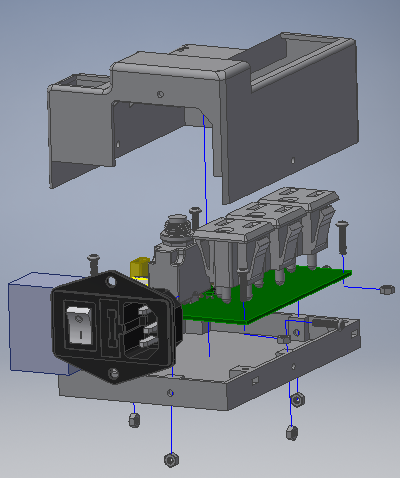
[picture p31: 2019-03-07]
Junior Design Documentation/Poster/Front_Exploded.png

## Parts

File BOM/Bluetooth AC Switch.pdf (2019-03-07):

BOM Name | Bluetooth AC Switch
Date | 20 Nov 2018; 19:06:24 GMT
Last update by user | bruslinj@oregonstate.edu
Created by user | bruslinj@oregonstate.edu
Revision | Latest
Part Number | Quantity | Cost | Supplier Part Number | Manufacturer
Vogek 3.1A 2-Pack Dual Port USB Wall Charger | 1 | 8.99 | N/A | Vogek
ORWH-SH-105D1F,000 | 3 | 1.35 | PB2032-ND TE Connectivity Potter & Brumfield Relays
739W-X2/32-A | 3 | 1.26 | Q1211-ND | Qualtek
ACS71020KMABTR-030B3-I2C | 1 | 5.26 | 620-1996-1-ND | Allegro MicroSystems, LLC
MAX40200AUK+T | 2 | 0.65 | MAX40200AUK+TCT-ND | Maxim Integrated
10103592-0001LF | 1 | 0.78 | 609-4048-1-ND | Amphenol ICC (FCI)
RC0201FR-071ML | 4 | 0.1 | 311-1MMCT-ND | Yageo
FSM4JRT | 2 | 0.17 | 450-2038-1-NDTE Connectivity ALCOSWITCH Switches
MBT2222ADW1T1G | 3 | 0.24 | MBT2222ADW1T1GOSCT-ND | ON Semiconductor
1N4148W-7-F | 3 | 0.18 | 1N4148W-FDICT-ND | Diodes Incorporated
W57-XB1A7A10-5 | 1 | 3.02 | PB1068-ND TE Connectivity Potter & Brumfield Relays
ACS722LLCTR-10AB-T | 2 | 5.54 | 620-1635-1-ND | Allegro MicroSystems, LLC
ESP32-WROOM-32 | 1 | 6.8 | 1904-1010-1-ND | Espressif Systems
LM1117MPX-3.3/NOPB | 1 | 1.14 | LM1117MPX-3.3/NOPBCT-ND | Texas Instruments
CP2102-GMR | 1 | 3.17 | 336-1160-1-ND | Silicon Labs

* = Available now

Supplier | Lead time | Description
Amazon | N/A | AC plug for microcontroller
Digikey | 4 Weeks | RELAY GEN PURPOSE SPDT 10A 5V
Digikey | 23 Weeks | 15A 125VAC NEMA 5-15R CONVENIENC
Digikey | 10 Weeks | SINGLE PHASE, ISOLATED, POWER MO
Digikey | 6 Weeks | IC DIODE CURRENT SWITCH SOT23-5
Digikey | 12 Weeks | CONN RCPT USB2.0 MICRO B SMD R/A
Digikey | 17 Weeks | RES SMD 1M OHM 1% 1/20W 0201
Digikey | 9 Weeks | SWITCH TACTILE SPST-NO 0.05A 24V
Digikey | 40 Weeks | TRANS 2NPN 40V 0.6A SOT363
Digikey | 32 Weeks | DIODE GEN PURP 100V 300MA SOD123
Digikey | 16 Weeks | CIR BRKR THRM 5A 250VAC
Digikey | Not Available | SENSOR CURRENT HALL 10A AC/DC
Digikey | 4 Weeks | SMD MODULE, ESP32-D0WDQ6, 32MBIT
Digikey | 8 Weeks | IC REG LIN 3.3V 800MA SOT223-4
Digikey | Not Available | IC USB-TO-UART BRIDGE 28VQFN

Component Name | Part State | Supplier Link | Total Cost
| In Progress | Amazon (https://www.amazon.com/dp/B07FS8QB21/ref=cm_sw_r_sms_awdb_t1_Yag9BbNQF8M81) | 8.99
K1, K2, K3 | In Progress | Digikey (https://www.digikey.com/product-detail/en/te-connectivity-potter-brumfield-relays/W57-XB1A7A10-5/PB1068-ND/1628639) | 4.05
J4, J5, J6 | In Progress | Digikey (https://www.digikey.com/product-detail/en/qualtek/739W-X2-32-A/Q1211-ND/8681866) | 3.78
U4 | In Progress | Digikey (https://www.digikey.com/product-detail/en/allegro-microsystems-llc/ACS71020KMABTR-030B3-I2C/620-1996-1-ND/9553641) | 5.26
D4, D5 | In Progress | Digikey (https://www.digikey.com/product-detail/en/maxim-integrated/MAX40200AUK-T/MAX40200AUK-TCT-ND/7599791) | 1.3
J3 | In Progress | Digikey (https://www.digikey.com/product-detail/en/amphenol-icc-fci/10103592-0001LF/609-4048-1-ND/2350355) | 0.78
R1, R2, R3, R6 | In Progress | Digikey (https://www.digikey.com/product-detail/en/yageo/RC0201FR-071ML/311-1MMCT-ND/4340582) | 0.4
S1, S2 | In Progress | Digikey (https://www.digikey.com/product-detail/en/te-connectivity-alcoswitch-switches/FSM4JRT/450-2038-1-ND/4146915) | 0.34
Q1, Q2, Q3 | In Progress | Digikey (https://www.digikey.com/product-detail/en/on-semiconductor/MBT2222ADW1T1G/MBT2222ADW1T1GOSCT-ND/2705031) | 0.72
D1, D2, D3 | In Progress | Digikey (https://www.digikey.com/product-detail/en/diodes-incorporated/1N4148W-7-F/1N4148W-FDICT-ND/815280) | 0.54
F1 | In Progress | Digikey (https://www.digikey.com/product-detail/en/te-connectivity-potter-brumfield-relays/W57-XB1A7A10-5/PB1068-ND/1628639) | 3.02
U2, U3 | In Progress | Digikey (https://www.digikey.com/product-detail/en/allegro-microsystems-llc/ACS722LLCTR-10AB-T/620-1635-1-ND/4948871) | 11.08
M1 | In Progress | Digikey (https://www.digikey.com/product-detail/en/espressif-systems/ESP32-WROOM-32/1904-1010-1-ND/8544305) | 6.8
U1 | In Progress | Digikey (https://www.digikey.com/product-detail/en/texas-instruments/LM1117MPX-3.3-NOPB/LM1117MPX-3.3-NOPBCT-ND/1010516) | 1.14
U5 | In Progress | Digikey (https://www.digikey.com/product-detail/en/silicon-labs/CP2102N-A01-GQFN20/336-3692-ND/6012517) | 3.17 00000000000000

Datasheet | Grand Total
N/A | 51.37
Datasheet (https://www.te.com/commerce/DocumentDelivery/DDEController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)
Datasheet (http://www.qualtekusa.com/images/AC_Receptacles/pdfs/739wx232a.pdf)
Datasheet (https://www.allegromicro.com/~/media/Files/Datasheets/ACS71020-Datasheet.ashx)
Datasheet (https://datasheets.maximintegrated.com/en/ds/MAX40200.pdf)
Datasheet (https://cdn.amphenol-icc.com/media/wysiwyg/files/drawing/10103592.pdf)
Datasheet (http://www.yageo.com/documents/recent/PYu-RC_Group_51_RoHS_L_10.pdf)
Datasheet (https://www.te.com/commerce/DocumentDelivery/DDEController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)
Datasheet (https://www.onsemi.com/pub/Collateral/MBT2222ADW1T1-D.PDF)
Datasheet (https://www.digikey.com/product-detail/en/diodes-incorporated/1N4148W-7-F/1N4148W-FDICT-ND/815280)
Datasheet (https://www.te.com/commerce/DocumentDelivery/DDEController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)
Datasheet (https://www.allegromicro.com/~/media/Files/Datasheets/ACS722-Datasheet.ashx)
Datasheet (https://www.espressif.com/sites/default/files/documentation/esp32-wroom-32_datasheet_en.pdf)
Datasheet (http://www.ti.com/lit/ds/symlink/lm1117.pdf)
Datasheet (https://www.silabs.com/documents/public/data-sheets/cp2102n-datasheet.pdf)

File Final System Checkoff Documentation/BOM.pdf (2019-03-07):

BOM Name | Bluetooth AC Switch
Date | 20 Nov 2018; 19:06:24 GMT
Last update by user | hallmac@oregonstate.edu
Created by user | bruslinj@oregonstate.edu | | | | | * = Available now
Revision | Latest
Part Number | Quantity | Cost | Supplier Part Number | Manufacturer | Supplier | Lead time
Vogek 3.1A 2-Pack Dual Port USB Wall Charger | 1 | 8.99 | N/A | Vogek | Amazon | N/A
ORWH-SH-105D1F,000 | 3 | 1.35 | PB2032-ND | TE Connectivity Potter & Brumfield Relays | Digikey | 4 Weeks
739W-X2/32-A | 3 | 1.26 | Q1211-ND | Qualtek | Digikey | 23 Weeks
ACS71020KMABTR-030B3-I2C | 1 | 5.26 | 620-1996-1-ND | Allegro MicroSystems, LLC | Digikey | 10 Weeks
MAX40200AUK+T | 2 | 0.65 | MAX40200AUK+TCT-ND | Maxim Integrated | Digikey | 6 Weeks
10103592-0001LF | 1 | 0.78 | 609-4048-1-ND | Amphenol ICC (FCI) | Digikey | 12 Weeks
RC0201FR-071ML | 4 | 0.1 | 311-1MMCT-ND | Yageo | Digikey | 17 Weeks
FSM4JRT | 2 | 0.17 | 450-2038-1-ND | TE Connectivity ALCOSWITCH Switches | Digikey | 9 Weeks
MBT2222ADW1T1G | 3 | 0.24 | MBT2222ADW1T1GOSCT-ND | ON Semiconductor | Digikey | 40 Weeks
1N4148W-7-F | 3 | 0.18 | 1N4148W-FDICT-ND | Diodes Incorporated | Digikey | 32 Weeks
W57-XB1A7A10-5 | 1 | 3.02 | PB1068-ND | TE Connectivity Potter & Brumfield Relays | Digikey | 16 Weeks
ACS722LLCTR-10AB-T | 2 | 5.54 | 620-1635-1-ND | Allegro MicroSystems, LLC | Digikey | Not Available
ESP32-WROOM-32 | 1 | 6.8 | 1904-1010-1-ND | Espressif Systems | Digikey | 4 Weeks
LM1117MPX-3.3/NOPB | 1 | 1.14 | LM1117MPX-3.3/NOPBCT-ND | Texas Instruments | Digikey | 8 Weeks
CP2102-GMR | 1 | 3.17 | 336-1160-1-ND | Silicon Labs | Digikey | Not Available

Description | Component Name | Part State | Supplier Link | Total Cost | Datasheet | Grand Total
AC plug for microcontroller | In Progress | Amazon | 8.99 | N/A | 51.37
RELAY GEN PURPOSE SPDT 10A 5V | K1, K2, K3 | In Progress | Digikey | 4.05 | Datasheet
15A 125VAC NEMA 5-15R CONVENIENC | J4, J5, J6 | In Progress | Digikey | 3.78 | Datasheet
SINGLE PHASE, ISOLATED, POWER MO | U4 | In Progress | Digikey | 5.26 | Datasheet
IC DIODE CURRENT SWITCH SOT23-5 | D4, D5 | In Progress | Digikey | 1.3 | Datasheet
CONN RCPT USB2.0 MICRO B SMD R/A | J3 | In Progress | Digikey | 0.78 | Datasheet
RES SMD 1M OHM 1% 1/20W 0201 | R1, R2, R3, R6 | In Progress | Digikey | 0.4 | Datasheet
SWITCH TACTILE SPST-NO 0.05A 24V | S1, S2 | In Progress | Digikey | 0.34 | Datasheet
TRANS 2NPN 40V 0.6A SOT363 | Q1, Q2, Q3 | In Progress | Digikey | 0.72 | Datasheet
DIODE GEN PURP 100V 300MA SOD123 | D1, D2, D3 | In Progress | Digikey | 0.54 | Datasheet
CIR BRKR THRM 5A 250VAC | F1 | In Progress | Digikey | 3.02 | Datasheet
SENSOR CURRENT HALL 10A AC/DC | U2, U3 | In Progress | Digikey | 11.08 | Datasheet
SMD MODULE, ESP32-D0WDQ6, 32MBIT | M1 | In Progress | Digikey | 6.8 | Datasheet
IC REG LIN 3.3V 800MA SOT223-4 | U1 | In Progress | Digikey | 1.14 | Datasheet
IC USB-TO-UART BRIDGE 28VQFN | U5 | In Progress | Digikey | 3.17 | Datasheet 00000000000000

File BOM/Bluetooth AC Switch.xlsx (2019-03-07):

BOM Name | Bluetooth AC Switch
Date | 20 Nov 2018; 19:06:24 GMT
Last update by user | hallmac@oregonstate.edu
Created by user | bruslinj@oregonstate.edu |  |  |  |  | * = Available now
Revision | Latest
Part Number | Quantity | Cost | Supplier Part Number | Manufacturer | Supplier | Lead time | Description | Component Name | Part State | Supplier Link | Total Cost | Datasheet | Grand Total
Vogek 3.1A 2-Pack Dual Port USB Wall Charger | 1 | 8.99 | N/A | Vogek | Amazon | N/A | AC plug for microcontroller |  | In Progress | Amazon (https://www.amazon.com/dp/B07FS8QB21/ref=cm_sw_r_sms_awdb_t1_Yag9BbNQF8M81) | 8.99 | N/A | 51.37
ORWH-SH-105D1F,000 | 3 | 1.35 | PB2032-ND | TE Connectivity Potter & Brumfield Relays | Digikey | 4 Weeks | RELAY GEN PURPOSE SPDT 10A 5V | K1, K2, K3 | In Progress | Digikey (https://www.digikey.com/product-detail/en/te-connectivity-potter-brumfield-relays/W57-XB1A7A10-5/PB1068-ND/1628639) | 4.05 | Datasheet (https://www.te.com/commerce/DocumentDelivery/DDEController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)
739W-X2/32-A | 3 | 1.26 | Q1211-ND | Qualtek | Digikey | 23 Weeks | 15A 125VAC NEMA 5-15R CONVENIENC | J4, J5, J6 | In Progress | Digikey (https://www.digikey.com/product-detail/en/qualtek/739W-X2-32-A/Q1211-ND/8681866) | 3.78 | Datasheet (http://www.qualtekusa.com/images/AC_Receptacles/pdfs/739wx232a.pdf)
ACS71020KMABTR-030B3-I2C | 1 | 5.26 | 620-1996-1-ND | Allegro MicroSystems, LLC | Digikey | 10 Weeks | SINGLE PHASE, ISOLATED, POWER MO | U4 | In Progress | Digikey (https://www.digikey.com/product-detail/en/allegro-microsystems-llc/ACS71020KMABTR-030B3-I2C/620-1996-1-ND/9553641) | 5.26 | Datasheet (https://www.allegromicro.com/~/media/Files/Datasheets/ACS71020-Datasheet.ashx)
MAX40200AUK+T | 2 | 0.65 | MAX40200AUK+TCT-ND | Maxim Integrated | Digikey | 6 Weeks | IC DIODE CURRENT SWITCH SOT23-5 | D4, D5 | In Progress | Digikey (https://www.digikey.com/product-detail/en/maxim-integrated/MAX40200AUK-T/MAX40200AUK-TCT-ND/7599791) | 1.3 | Datasheet (https://datasheets.maximintegrated.com/en/ds/MAX40200.pdf)
10103592-0001LF | 1 | 0.78 | 609-4048-1-ND | Amphenol ICC (FCI) | Digikey | 12 Weeks | CONN RCPT USB2.0 MICRO B SMD R/A | J3 | In Progress | Digikey (https://www.digikey.com/product-detail/en/amphenol-icc-fci/10103592-0001LF/609-4048-1-ND/2350355) | 0.78 | Datasheet (https://cdn.amphenol-icc.com/media/wysiwyg/files/drawing/10103592.pdf)
RC0201FR-071ML | 4 | 0.1 | 311-1MMCT-ND | Yageo | Digikey | 17 Weeks | RES SMD 1M OHM 1% 1/20W 0201 | R1, R2, R3, R6 | In Progress | Digikey (https://www.digikey.com/product-detail/en/yageo/RC0201FR-071ML/311-1MMCT-ND/4340582) | 0.4 | Datasheet (http://www.yageo.com/documents/recent/PYu-RC_Group_51_RoHS_L_10.pdf)
FSM4JRT | 2 | 0.17 | 450-2038-1-ND | TE Connectivity ALCOSWITCH Switches | Digikey | 9 Weeks | SWITCH TACTILE SPST-NO 0.05A 24V | S1, S2 | In Progress | Digikey (https://www.digikey.com/product-detail/en/te-connectivity-alcoswitch-switches/FSM4JRT/450-2038-1-ND/4146915) | 0.34 | Datasheet (https://www.te.com/commerce/DocumentDelivery/DDEController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)
MBT2222ADW1T1G | 3 | 0.24 | MBT2222ADW1T1GOSCT-ND | ON Semiconductor | Digikey | 40 Weeks | TRANS 2NPN 40V 0.6A SOT363 | Q1, Q2, Q3 | In Progress | Digikey (https://www.digikey.com/product-detail/en/on-semiconductor/MBT2222ADW1T1G/MBT2222ADW1T1GOSCT-ND/2705031) | 0.72 | Datasheet (https://www.onsemi.com/pub/Collateral/MBT2222ADW1T1-D.PDF)
1N4148W-7-F | 3 | 0.18 | 1N4148W-FDICT-ND | Diodes Incorporated | Digikey | 32 Weeks | DIODE GEN PURP 100V 300MA SOD123 | D1, D2, D3 | In Progress | Digikey (https://www.digikey.com/product-detail/en/diodes-incorporated/1N4148W-7-F/1N4148W-FDICT-ND/815280) | 0.54 | Datasheet (https://www.digikey.com/product-detail/en/diodes-incorporated/1N4148W-7-F/1N4148W-FDICT-ND/815280)
W57-XB1A7A10-5 | 1 | 3.02 | PB1068-ND | TE Connectivity Potter & Brumfield Relays | Digikey | 16 Weeks | CIR BRKR THRM 5A 250VAC | F1 | In Progress | Digikey (https://www.digikey.com/product-detail/en/te-connectivity-potter-brumfield-relays/W57-XB1A7A10-5/PB1068-ND/1628639) | 3.02 | Datasheet (https://www.te.com/commerce/DocumentDelivery/DDEController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)
ACS722LLCTR-10AB-T | 2 | 5.54 | 620-1635-1-ND | Allegro MicroSystems, LLC | Digikey | Not Available | SENSOR CURRENT HALL 10A AC/DC | U2, U3 | In Progress | Digikey (https://www.digikey.com/product-detail/en/allegro-microsystems-llc/ACS722LLCTR-10AB-T/620-1635-1-ND/4948871) | 11.08 | Datasheet (https://www.allegromicro.com/~/media/Files/Datasheets/ACS722-Datasheet.ashx)
ESP32-WROOM-32 | 1 | 6.8 | 1904-1010-1-ND | Espressif Systems | Digikey | 4 Weeks | SMD MODULE, ESP32-D0WDQ6, 32MBIT | M1 | In Progress | Digikey (https://www.digikey.com/product-detail/en/espressif-systems/ESP32-WROOM-32/1904-1010-1-ND/8544305) | 6.8 | Datasheet (https://www.espressif.com/sites/default/files/documentation/esp32-wroom-32_datasheet_en.pdf)
LM1117MPX-3.3/NOPB | 1 | 1.14 | LM1117MPX-3.3/NOPBCT-ND | Texas Instruments | Digikey | 8 Weeks | IC REG LIN 3.3V 800MA SOT223-4 | U1 | In Progress | Digikey (https://www.digikey.com/product-detail/en/texas-instruments/LM1117MPX-3.3-NOPB/LM1117MPX-3.3-NOPBCT-ND/1010516) | 1.14 | Datasheet (http://www.ti.com/lit/ds/symlink/lm1117.pdf)
CP2102-GMR | 1 | 3.17 | 336-1160-1-ND | Silicon Labs | Digikey | Not Available | IC USB-TO-UART BRIDGE 28VQFN | U5 | In Progress | Digikey (https://www.digikey.com/product-detail/en/silicon-labs/CP2102N-A01-GQFN20/336-3692-ND/6012517) | 3.17 | Datasheet (https://www.silabs.com/documents/public/data-sheets/cp2102n-datasheet.pdf)
 |  |  |  |  |  |  |  |  |  |  | 0
 |  |  |  |  |  |  |  |  |  |  | 0
 |  |  |  |  |  |  |  |  |  |  | 0
 |  |  |  |  |  |  |  |  |  |  | 0
 |  |  |  |  |  |  |  |  |  |  | 0
 |  |  |  |  |  |  |  |  |  |  | 0
 |  |  |  |  |  |  |  |  |  |  | 0
 |  |  |  |  |  |  |  |  |  |  | 0
 |  |  |  |  |  |  |  |  |  |  | 0
 |  |  |  |  |  |  |  |  |  |  | 0
 |  |  |  |  |  |  |  |  |  |  | 0
 |  |  |  |  |  |  |  |  |  |  | 0
 |  |  |  |  |  |  |  |  |  |  | 0
 |  |  |  |  |  |  |  |  |  |  | 0

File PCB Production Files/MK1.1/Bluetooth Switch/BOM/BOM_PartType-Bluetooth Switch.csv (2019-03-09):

Capacitance | Resistance | Case/Package | Case/Package (SI) | Package/Case | Comment | Description | Designator | Quantity
 |  |  |  |  | LED | LED; PCB ; Green; 0.63mcd; 3mm; T-1; 7mA; 1.9V; 565nm; 25deg; GaP on GaP; 20V; 20mW; -40 | 3_3V | 1
 |  |  |  |  | LED | LED; PCB ; Green; 0.63mcd; 3mm; T-1; 7mA; 1.9V; 565nm; 25deg; GaP on GaP; 20V; 20mW; -40 | 5V | 1
 | 5.1K Ohms | 1206 (3216) |  |  | 1206 (3216) | Generic Resistor pad 1206 Imperial and 3216 Metric | ACS710_R_Sense | 1
10.0 µF |  |  |  |  | 10uF | Capacitor Tantalum Solid 10uF 25V 10% (5.5 X 9mm) Radial 2.5mm 2.5 Ohm 125C Bulk | C1 | 1
10.0 µF |  |  |  |  | 10uF | Capacitor Tantalum Solid 10uF 25V 10% (5.5 X 9mm) Radial 2.5mm 2.5 Ohm 125C Bulk | C2 | 1
10.0 µF |  |  |  |  | 10uF | Capacitor Tantalum Solid 10uF 25V 10% (5.5 X 9mm) Radial 2.5mm 2.5 Ohm 125C Bulk | C3 | 1
 |  |  |  | 3216 (SI) | .1uF | Cap Ceramic 1uF 25V X7R 20% SMD 1206 125C Plastic T/R | C4 | 1
 |  |  |  | 3216 (SI) | 1uF | Cap Ceramic 1uF 25V X7R 20% SMD 1206 125C Plastic T/R | C5 | 1
 |  |  |  | 3216 (SI) | .1uF | Cap Ceramic 1uF 25V X7R 20% SMD 1206 125C Plastic T/R | C6 | 1
 |  |  |  | 3216 (SI) | .1uF | Cap Ceramic 1uF 25V X7R 20% SMD 1206 125C Plastic T/R | C7 | 1
 |  |  |  | 3216 (SI) | .1uF | Cap Ceramic 1uF 25V X7R 20% SMD 1206 125C Plastic T/R | C8 | 1
 |  | SOD-123 |  |  | 1N4148 | Fast Switching Diode, 100V, 400mW, Surface Mount, SOD-123 | D1 | 1
 |  | SOD-123 |  |  | 1N4148 | Fast Switching Diode, 100V, 400mW, Surface Mount, SOD-123 | D2 | 1
 |  | SOD-123 |  |  | 1N4148 | Fast Switching Diode, 100V, 400mW, Surface Mount, SOD-123 | D3 | 1
 |  |  |  |  | Maxim Integrated MAX40200AUK+T | MAX40200AUK Seires 5.5 V 1 A MicropowerCurrent Switch Diode - SOT23-5 | D4 | 1
 |  |  |  |  | Maxim Integrated MAX40200AUK+T | MAX40200AUK Seires 5.5 V 1 A MicropowerCurrent Switch Diode - SOT23-5 | D5 | 1
 |  |  |  |  | SYM-889e43fc15205759-1 | Thermal Circuit Breaker, Push to Reset, 250VAC, 5AMP, .250 Quick Connect | F1 | 1
 |  |  |  |  | XT30 | Very similar to the XT60 models, but smaller and made for 30A | J1 | 1
 |  |  |  |  | Würth Elektronik 61300311121 | Board-To-Board Connector, Vertical, Wr-Phd Series, Through Hole, Header, 3, 2.54 Mm | J2 | 1
 |  |  |  |  | TE Connectivity / AMP 292304-1 | Surface Mount Right Angle USB B Connector | J3 | 1
 |  |  |  |  | Qualtek 739W-X2/32 | Receptacle; Female; Convenience Outlet; NEMA 5-15R; PCB Terminals; Black; 15A; 125VAC | J4 | 1
 |  |  |  |  | Qualtek 739W-X2/32 | Receptacle; Female; Convenience Outlet; NEMA 5-15R; PCB Terminals; Black; 15A; 125VAC | J5 | 1
 |  |  |  |  | Qualtek 739W-X2/32 | Receptacle; Female; Convenience Outlet; NEMA 5-15R; PCB Terminals; Black; 15A; 125VAC | J6 | 1
 |  |  |  |  |  | Electromechanical Relay 5VDC 15A SPDT (( 19.2mm 15.5mm 15mm)) THT General Purpose Relay | K1 | 1
 |  |  |  |  |  | Electromechanical Relay 5VDC 15A SPDT (( 19.2mm 15.5mm 15mm)) THT General Purpose Relay | K2 | 1
 |  |  |  |  |  | Electromechanical Relay 5VDC 15A SPDT (( 19.2mm 15.5mm 15mm)) THT General Purpose Relay | K3 | 1
 |  |  |  |  | Espressif Systems ESP32-WROOM-32 | Wi-Fi/BT BLE Module ESP32-D0WDQ6, SPI Flash, UART | M1 | 1
 |  |  |  |  | LED | LED; PCB ; Green; 0.63mcd; 3mm; T-1; 7mA; 1.9V; 565nm; 25deg; GaP on GaP; 20V; 20mW; -40 | N1 | 1
 |  |  |  |  | LED | LED; PCB ; Green; 0.63mcd; 3mm; T-1; 7mA; 1.9V; 565nm; 25deg; GaP on GaP; 20V; 20mW; -40 | N2 | 1
 |  |  |  |  | LED | LED; PCB ; Green; 0.63mcd; 3mm; T-1; 7mA; 1.9V; 565nm; 25deg; GaP on GaP; 20V; 20mW; -40 | N3 | 1
 |  | SOT-363 |  |  | MBT2222ADW1T1G | General Purpose Transistor, NPN Silicon, 6-Pin SOT-363, Pb-Free, Tape and Reel | Q1 | 1
 |  | SOT-363 |  |  | MBT2222ADW1T1G | General Purpose Transistor, NPN Silicon, 6-Pin SOT-363, Pb-Free, Tape and Reel | Q2 | 1
 |  | SOT-363 |  |  | MBT2222ADW1T1G | General Purpose Transistor, NPN Silicon, 6-Pin SOT-363, Pb-Free, Tape and Reel | Q3 | 1
 | 1.00 M | 0603 (SI) |  |  | Yageo RC0201FR-071ML | Res Thick Film 0201 1M Ohm 1% 1/20W ±200ppm/°C Molded SMD SMD Paper T/R | R1 | 1
 | 1.00 M | 0603 (SI) |  |  | Yageo RC0201FR-071ML | Res Thick Film 0201 1M Ohm 1% 1/20W ±200ppm/°C Molded SMD SMD Paper T/R | R2 | 1
 | 1.00 M | 0603 (SI) |  |  | Yageo RC0201FR-071ML | Res Thick Film 0201 1M Ohm 1% 1/20W ±200ppm/°C Molded SMD SMD Paper T/R | R3 | 1
 | 1.5K |  |  | 2012 | Vishay Dale TNPU0805100KBZEN00 | Thin Film Resistors - SMD 1/8watt 100Kohms 0.1% 5ppm | R4 | 1
 | 3.48K |  |  | 2012 | Vishay Dale TNPU0805100KBZEN00 | Thin Film Resistors - SMD 1/8watt 100Kohms 0.1% 5ppm | R5 | 1
 | 1.00 M | 0603 (SI) |  |  | Yageo RC0201FR-071ML | Res Thick Film 0201 1M Ohm 1% 1/20W ±200ppm/°C Molded SMD SMD Paper T/R | R6 | 1
 | 12K | 0805 | 2012 |  | Panasonic ERJ-6GEYJ822V | Thick Film Resistors - SMD 0805 8.2Kohms 5% Tol | R7 | 1
 | 470 | 0805 | 2012 |  | Panasonic ERJ-6GEYJ822V | Thick Film Resistors - SMD 0805 8.2Kohms 5% Tol | R8 | 1
 | 12K | 0805 | 2012 |  | Panasonic ERJ-6GEYJ822V | Thick Film Resistors - SMD 0805 8.2Kohms 5% Tol | R9 | 1
 | 470 | 0805 | 2012 |  | Panasonic ERJ-6GEYJ822V | Thick Film Resistors - SMD 0805 8.2Kohms 5% Tol | R10 | 1
 | 12K | 0805 | 2012 |  | Panasonic ERJ-6GEYJ822V | Thick Film Resistors - SMD 0805 8.2Kohms 5% Tol | R11 | 1
 | 12K | 0805 | 2012 |  | Panasonic ERJ-6GEYJ822V | Thick Film Resistors - SMD 0805 8.2Kohms 5% Tol | R12 | 1
 | 1K | 0805 | 2012 |  | Panasonic ERJ-6GEYJ822V | Thick Film Resistors - SMD 0805 8.2Kohms 5% Tol | R13 | 1
 | 1K | 0805 | 2012 |  | Panasonic ERJ-6GEYJ822V | Thick Film Resistors - SMD 0805 8.2Kohms 5% Tol | R14 | 1
 | 1K | 0805 | 2012 |  | Panasonic ERJ-6GEYJ822V | Thick Film Resistors - SMD 0805 8.2Kohms 5% Tol | R15 | 1
 | 1K | 0805 | 2012 |  | Panasonic ERJ-6GEYJ822V | Thick Film Resistors - SMD 0805 8.2Kohms 5% Tol | R16 | 1
 | 1K | 0805 | 2012 |  | Panasonic ERJ-6GEYJ822V | Thick Film Resistors - SMD 0805 8.2Kohms 5% Tol | R17 | 1
 | 1K | 0805 | 2012 |  | Panasonic ERJ-6GEYJ822V | Thick Film Resistors - SMD 0805 8.2Kohms 5% Tol | R18 | 1
 | 1K | 0805 | 2012 |  | Panasonic ERJ-6GEYJ822V | Thick Film Resistors - SMD 0805 8.2Kohms 5% Tol | R19 | 1
 | 1K | 0805 | 2012 |  | Panasonic ERJ-6GEYJ822V | Thick Film Resistors - SMD 0805 8.2Kohms 5% Tol | R20 | 1
 | 470 | 0805 | 2012 |  | Panasonic ERJ-6GEYJ822V | Thick Film Resistors - SMD 0805 8.2Kohms 5% Tol | R21 | 1
 | 1K | 0805 | 2012 |  | Panasonic ERJ-6GEYJ822V | Thick Film Resistors - SMD 0805 8.2Kohms 5% Tol | R22 | 1
 | 1K | 0805 | 2012 |  | Panasonic ERJ-6GEYJ822V | Thick Film Resistors - SMD 0805 8.2Kohms 5% Tol | R23 | 1
 |  |  |  |  | TE Connectivity FSM4JH | Switch Tactile OFF (ON) Round Button PC Pins 0.05A 12VDC 1.57N Thru-Hole Radial Tape | S1 | 1
 |  |  |  |  | TE Connectivity FSM4JH | Switch Tactile OFF (ON) Round Button PC Pins 0.05A 12VDC 1.57N Thru-Hole Radial Tape | S2 | 1
 |  |  |  |  | Texas Instruments (TI) LM1117MPX-ADJ/NOPB | LDO Regulator Pos 1.25V to 13.8V 0.8A 4-Pin(3+Tab) SOT-223 T/R | U1 | 1
 |  |  |  |  | ACS722LLCTR-40AU-T | CURRENT SENSOR, 0.009A, NSOIC-8; Quiescent Current:9mA; Bandwidth:80kHz; Sensor Case Style:NSOIC; No. of Pins:8; Supply Voltage Min:3V; Supply Voltage Max:3.6V; Operating Temperature Min:-40 C; Operat | U2 | 1
 |  |  |  |  | ACS722LLCTR-40AU-T | CURRENT SENSOR, 0.009A, NSOIC-8; Quiescent Current:9mA; Bandwidth:80kHz; Sensor Case Style:NSOIC; No. of Pins:8; Supply Voltage Min:3V; Supply Voltage Max:3.6V; Operating Temperature Min:-40 C; Operat | U3 | 1
 |  |  |  |  | Allegro MicroSystems LLC ACS71020KMABTR-030B3-I2C | Single Phase, Isolated, Power Mo, +/-30A,3V3, 16 SOIC W | U4 | 1
 |  | MLP |  |  | Silicon Labs CP2102-GM | Microcontroller Solutions - Interface Products USB to UART Bdg Chip | U5 | 1

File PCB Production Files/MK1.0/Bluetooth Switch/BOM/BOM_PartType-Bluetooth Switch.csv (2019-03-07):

Capacitance | Resistance | Case/Package | Case/Package (SI) | Package/Case | Comment | Description | Designator | Digikey | Footprint | LibRef | Quantity | Purchasing
 |  |  |  |  | LED | LED; PCB ; Green; 0.63mcd; 3mm; T-1; 7mA; 1.9V; 565nm; 25deg; GaP on GaP; 20V; 20mW; -40 | 3_3V, 5V, N1, N2, N3 |  | PCB-a4kbstwpa15hyka10z5q-1 | CMP-afe165a651817026-6 | 5 | Already have in hand
 |  |  |  |  | Würth Elektronik 61300311121 | Board-To-Board Connector, Vertical, Wr-Phd Series, Through Hole, Header, 3, 2.54 Mm | J2 |  | PCB-4c070sxu9rgckamhssqs-1 | CMP-8a90426ffa175557-17 | 1 | Already have in hand
 |  |  |  |  | Pololu XT60 YELLOW | Power connector; 65A; PIN: 2; Module: yellow | J1 |  | PCB-42h2ntsp5e5udn23h2hi-1 | CMP-db0d1124dea204ca-7 | 1 | Amazon
 | 5.1K |  |  | 3216 | Res1 | Resistor; Thick Film; Res 0.005 Ohms; Pwr-Rtg 1 W; Tol 1%; SMT; 2512; Curr-Sense; CT | ACS710_R_Sense |  | PCB-w608zr93f2jrqwdmzt1l-1 | CMP-027ac92f87baddbd-2 | 1 | Digikey
 |  | SOD-123 |  |  | 1N4148 | Fast Switching Diode, 100V, 400mW, Surface Mount, SOD-123 | D1, D2, D3 |  | PCB-1N4148W-7-F | CMP-791fb3587d52a6d8-18 | 3 | Digikey
 |  |  |  |  | Maxim Integrated MAX40200AUK+T | MAX40200AUK Seires 5.5 V 1 A MicropowerCurrent Switch Diode - SOT23-5 | D4, D5 |  | PCB-5992oh1g9ftksyaw6nl7-1 | CMP-ca4407a63c661583-2 | 2 | Digikey
 |  |  |  |  | SYM-889e43fc15205759-1 | Thermal Circuit Breaker, Push to Reset, 250VAC, 5AMP, .250 Quick Connect | F1 |  | PCB-832i69x6ehi1igon8e0u-1 | CMP-889e43fc15205759-2 | 1 | Digikey
 |  |  |  |  | FCI 10103592-0001LF | Conn Micro USB Type B RCP 5 POS 0.65mm Solder RA SMD 5 Terminal 1 Port T/R | J3 |  | PCB-93gureqnc5na2ljp2ys4-1 | CMP-714ab89b8005ae8d-14 | 1 | Digikey
 |  |  |  |  | Qualtek 739W-X2/32 | Receptacle; Female; Convenience Outlet; NEMA 5-15R; PCB Terminals; Black; 15A; 125VAC | J4, J5, J6 |  | PCB-67s0c3f5wkn5okutfpzj-1 | CMP-1fd6d3ae91e2c011-2 | 3 | Digikey
 |  |  |  |  | SYM-b9d97116e885661e-1 | General Purpose Relay, SRA Series, Power, Non Latching, SPDT, 12 VDC, 20 A | K1, K2, K3 | SONGLE SRA 20A | PCB-6zkvxj3q6xq20xnkkjg3-1 | CMP-b9d97116e885661e-3 | 3 | Digikey
 |  |  |  |  | Espressif Systems ESP32-WROOM-32 | Wi-Fi/BT BLE Module ESP32-D0WDQ6, SPI Flash, UART | M1 |  | PCB-2wsaxr5oyyiks99lfuw0-1 | CMP-ba1676706f1765d1-4 | 1 | Digikey
 |  | SOT-363 |  |  | MBT2222ADW1T1G | General Purpose Transistor, NPN Silicon, 6-Pin SOT-363, Pb-Free, Tape and Reel | Q1, Q2, Q3 |  | ONSC-SOT-363-6-419B-02_V | CMP-854660-2 | 3 | Digikey
 | 1.00 M | 0603 (SI) |  |  | Yageo RC0201FR-071ML | Res Thick Film 0201 1M Ohm 1% 1/20W ±200ppm/°C Molded SMD SMD Paper T/R | R1, R2, R3, R6 |  | PCB-izhuxvfgpg1kpuec29hj-1 | CMP-002acbb13d71dfed-1 | 4 | Digikey
 |  |  |  |  | TE Connectivity FSM4JH | Switch Tactile OFF (ON) Round Button PC Pins 0.05A 12VDC 1.57N Thru-Hole Radial Tape | S1, S2 |  | PCB-acd06xmd0wg5ueuxhpdp-1 | CMP-441d8f7279709bda-7 | 2 | Digikey
 |  |  |  |  | Texas Instruments (TI) LM1117MPX-ADJ/NOPB | LDO Regulator Pos 1.25V to 13.8V 0.8A 4-Pin(3+Tab) SOT-223 T/R | U1 |  | SOT223 | CMP-0062-01644-5 | 1 | Digikey
 |  |  |  |  | ACS722LLCTR-40AU-T | CURRENT SENSOR, 0.009A, NSOIC-8; Quiescent Current:9mA; Bandwidth:80kHz; Sensor Case Style:NSOIC; No. of Pins:8; Supply Voltage Min:3V; Supply Voltage Max:3.6V; Operating Temperature Min:-40 C; Operat | U2, U3 |  | TI-D8_N | CMP-19553975-3 | 2 | Digikey
 |  |  |  |  | Allegro MicroSystems LLC ACS71020KMABTR-030B3-I2C | Single Phase, Isolated, Power Mo, +/-30A,3V3, 16 SOIC W | U4 |  | ACS71020 | CMP-c7eb0b7c5e75182c-1 | 1 | Digikey
 |  | MLP |  |  | Silicon Labs CP2102-GM | Microcontroller Solutions - Interface Products USB to UART Bdg Chip | U5 |  | PCB-r2q4wj0b96jlqp92htuq-1 | CMP-967561-7 | 1 | Digikey
10.0 µF |  |  |  |  | 10uF | Capacitor Tantalum Solid 10uF 25V 10% (5.5 X 9mm) Radial 2.5mm 2.5 Ohm 125C Bulk | C1, C2, C3 |  | PCB-imxzc0h3ulzopa7zwnih-1 | CMP-6a29a3234e15b5ee-2 | 3 | Resistore
 |  |  |  | 3216 (SI) | .1uF | Cap Ceramic 1uF 25V X7R 20% SMD 1206 125C Plastic T/R | C4, C6, C7, C8 |  | CSMD1206GRID25PADB | CMP-150561-3 | 4 | Resistore
 |  |  |  | 3216 (SI) | 1uF | Cap Ceramic 1uF 25V X7R 20% SMD 1206 125C Plastic T/R | C5 |  | CSMD1206GRID25PADB | CMP-150561-3 | 1 | Resistore
 | 1.5K |  |  | 2012 | Vishay Dale TNPU0805100KBZEN00 | Thin Film Resistors - SMD 1/8watt 100Kohms 0.1% 5ppm | R4 |  | RESC2013X55X40NL15T20 | CMP-1878956-2 | 1 | Resistore
 | 3.48K |  |  | 2012 | Vishay Dale TNPU0805100KBZEN00 | Thin Film Resistors - SMD 1/8watt 100Kohms 0.1% 5ppm | R5 |  | RESC2013X55X40NL15T20 | CMP-1878956-2 | 1 | Resistore
 | 12K | 805 | 2012 |  | Panasonic ERJ-6GEYJ822V | Thick Film Resistors - SMD 0805 8.2Kohms 5% Tol | R7, R9, R11, R12 |  | RESC2013X70X40ML20T20 | CMP-3687578-2 | 4 | Resistore
 | 470 | 805 | 2012 |  | Panasonic ERJ-6GEYJ822V | Thick Film Resistors - SMD 0805 8.2Kohms 5% Tol | R8, R10, R21 |  | RESC2013X70X40ML20T20 | CMP-3687578-2 | 3 | Resistore
 | 1K | 805 | 2012 |  | Panasonic ERJ-6GEYJ822V | Thick Film Resistors - SMD 0805 8.2Kohms 5% Tol | R13, R14, R15, R16, R17, R18, R19, R20, R22, R23 |  | RESC2013X70X40ML20T20 | CMP-3687578-2 | 10 | Resistore

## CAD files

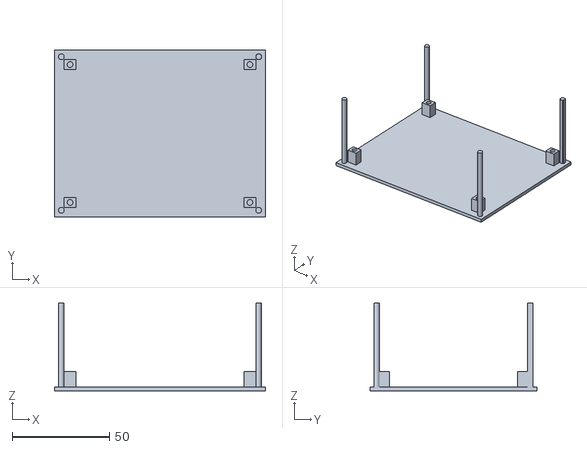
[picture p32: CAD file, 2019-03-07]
Case/Final_Bottom_fixed.stl
108.2 x 85.8 x 45.0

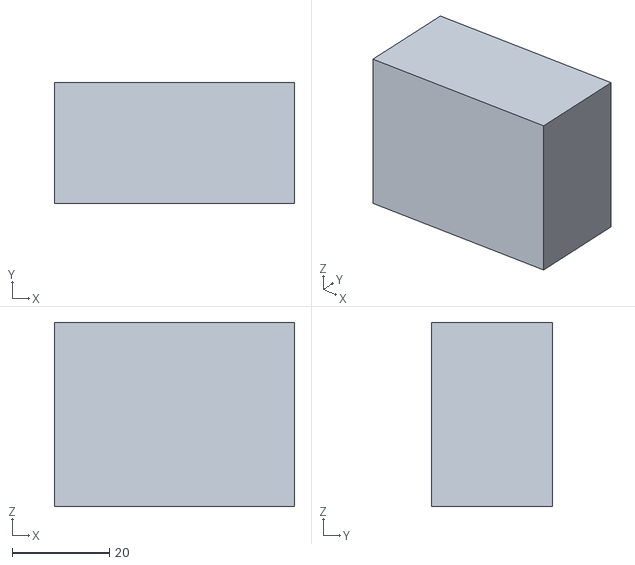
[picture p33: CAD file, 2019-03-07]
Junior Design Documentation/Misc. Files/Transformer.STL
49.4 x 25.0 x 38.0

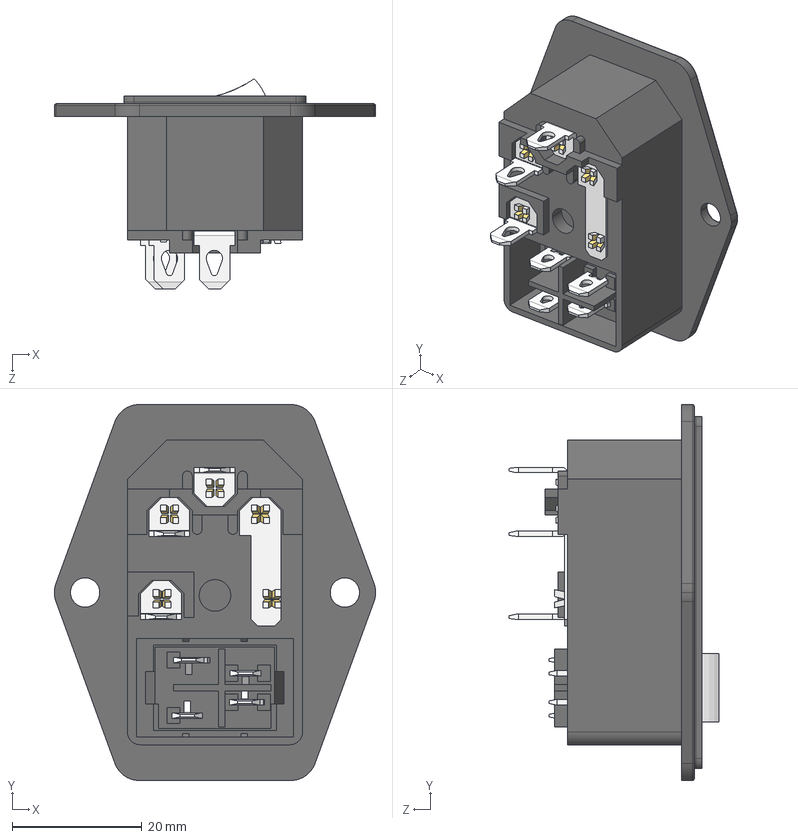
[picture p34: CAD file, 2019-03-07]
Case/IEC320-C14.STEP
49.5 x 57.9 x 32.4 mm
ilpm_case
fuse_clip_set
blade_15
blade_12 x 2
fuse-holder
fuse
switch_base
rocker
sm_tab_type1a
sm_tab_type1b
sm_tab_type2a
sm_tab_type2b
spot x 2
stamped_cond
correct_big_tab x 3

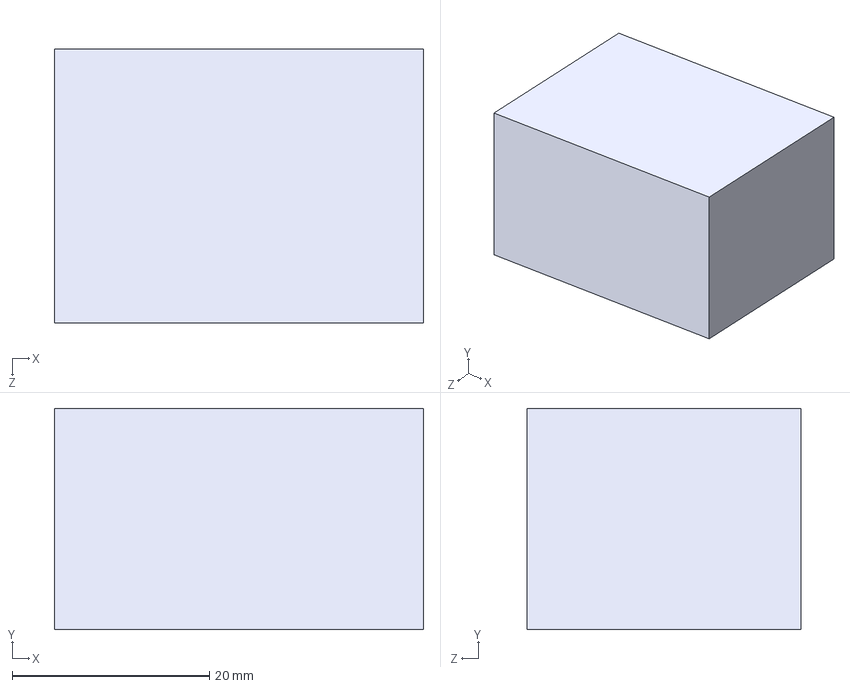
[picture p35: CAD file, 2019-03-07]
Junior Design Documentation/Misc. Files/Transformer4Dummy.STEP
37.5 x 22.4 x 27.8 mm

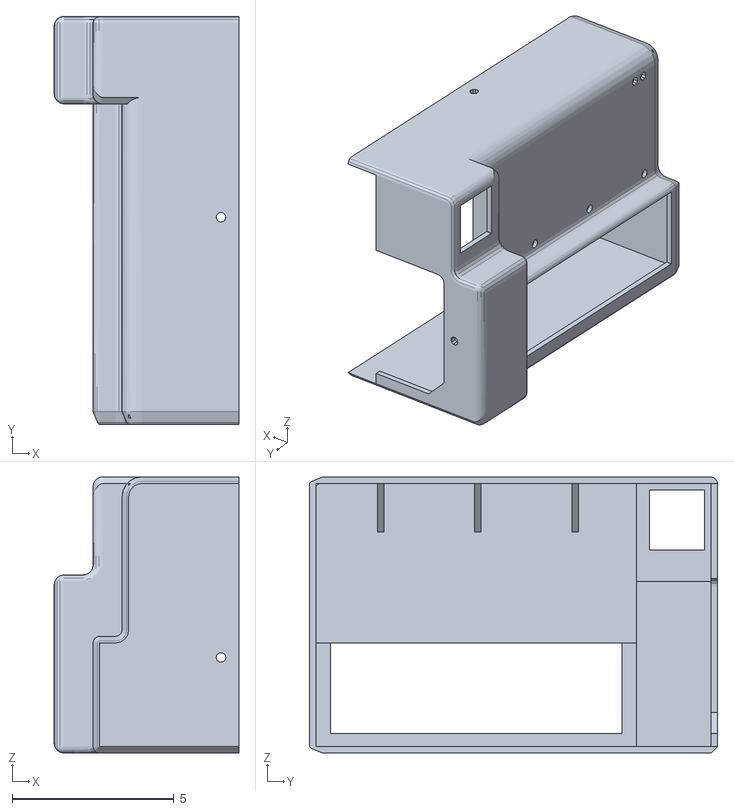
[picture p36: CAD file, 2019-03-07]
Case/Case_Cover.stl
5.70 x 12.6 x 8.52

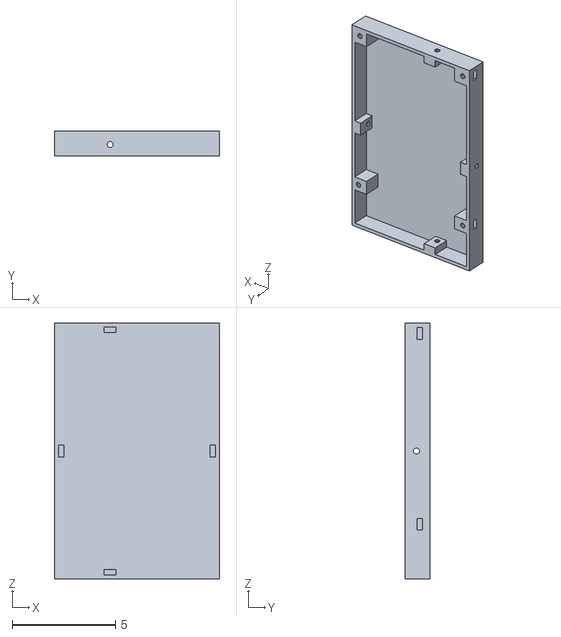
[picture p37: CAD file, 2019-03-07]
Case/Case_Top.stl
8.00 x 1.20 x 12.4

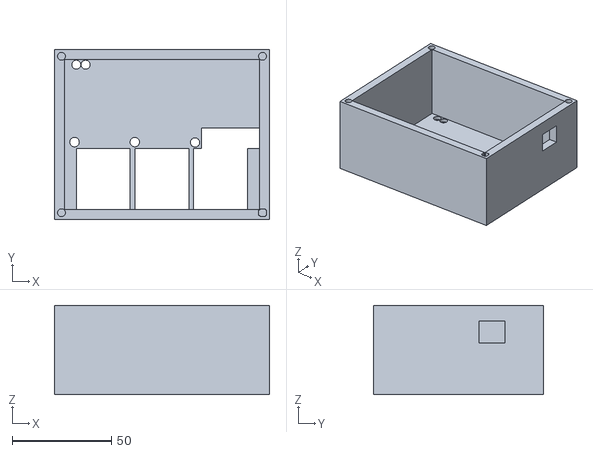
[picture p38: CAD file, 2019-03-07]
Case/Final_Top_V3_fixed.stl
108.2 x 85.8 x 45.0

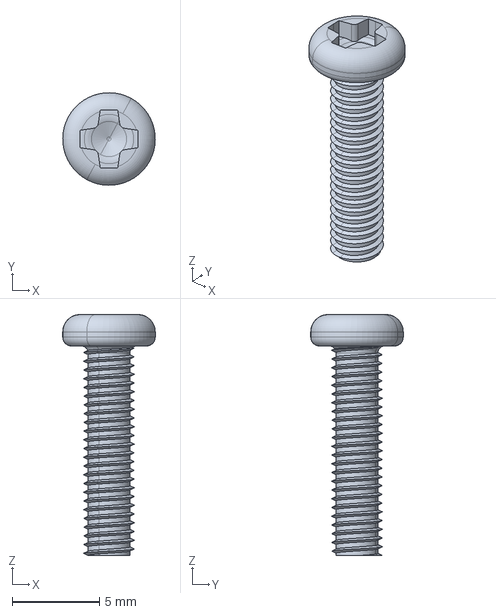
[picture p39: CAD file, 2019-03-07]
Case/M3x12 Philips Screw.stp
5.30 x 5.30 x 13.8 mm

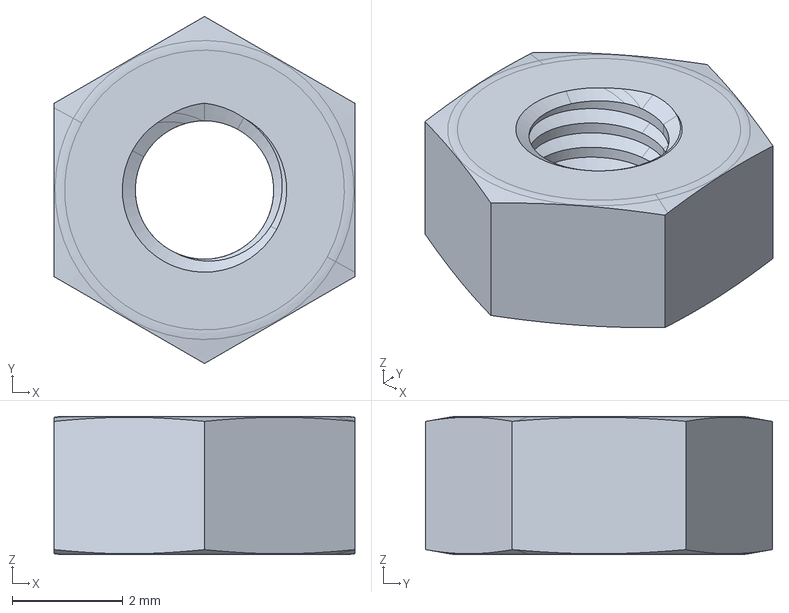
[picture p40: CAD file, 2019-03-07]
Case/M3 Nut.stp
5.43 x 6.27 x 2.50 mm

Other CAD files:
Case/Assembly99.iam
Case/Assembly99.ipn
Case/C14-Plug.ipt
Case/Case_Cover.ipt
Case/Case_Top.ipt
Case/Final_Bottom_fixed.skp
Case/Final_Top_V3_fixed.skp
Case/IEC320-C14.iam
Case/M3 Nut.ipt
Case/M3x12 Philips Screw.ipt
Case/OldVersions/Assembly99.0002.ipn
Case/OldVersions/Assembly99.0015.iam
Case/OldVersions/Assembly99.iam
Case/OldVersions/Assembly99.ipn
Case/OldVersions/C14-Plug.ipt
Case/OldVersions/Case_Cover.0037.ipt
Case/OldVersions/Case_Cover.0046.ipt
Case/OldVersions/Case_Cover.ipt
Case/OldVersions/Case_Top.0017.ipt
Case/OldVersions/Case_Top.ipt
Case/OldVersions/Final_Bottom_fixed.skp
Case/OldVersions/Final_Top_V3_fixed.skp
Case/OldVersions/IEC320-C14.0001.iam
Case/OldVersions/IEC320-C14.iam
Case/OldVersions/M3 Nut.ipt
Case/OldVersions/M3x12 Philips Screw.ipt
Case/OldVersions/Transformer4Dummy.0001.ipt
Case/OldVersions/Transformer4Dummy.ipt
Case/OldVersions/blade_12.ipt
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

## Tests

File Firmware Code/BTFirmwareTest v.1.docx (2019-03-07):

/*

Video: https://www.youtube.com/watch?v=oCMOYS71NIU

Based on Neil Kolban example for IDF: https://github.com/nkolban/esp32-snippets/blob/master/cpp_utils/tests/BLE%20Tests/SampleNotify.cpp

Ported to Arduino ESP32 by Evandro Copercini

Create a BLE server that, once we receive a connection, will send periodic notifications.

The service advertises itself as: 6E400001-B5A3-F393-E0A9-E50E24DCCA9E

Has a characteristic of: 6E400002-B5A3-F393-E0A9-E50E24DCCA9E - used for receiving data with "WRITE"

Has a characteristic of: 6E400003-B5A3-F393-E0A9-E50E24DCCA9E - used to send data with "NOTIFY"

The design of creating the BLE server is:

1. Create a BLE Server

2. Create a BLE Service

3. Create a BLE Characteristic on the Service

4. Create a BLE Descriptor on the characteristic

5. Start the service.

6. Start advertising.

In this example rxValue is the data received (only accessible inside that function).

And voltageValue is the data to be sent, in this example just a byte incremented every second.

*/

#include <BLEDevice.h>

#include <BLEServer.h>

#include <BLEUtils.h>

#include <BLE2902.h>

BLECharacteristic *pCharacteristic;

bool deviceConnected = false;

float txValue = 0;

const int readPin = 32; // Use GPIO number. See ESP32 board pinouts

const int RED = 25; // Could be different depending on the dev board. I used the DOIT ESP32 dev board.

const int GREEN = 26;

const int BLUE = 2;

int adder = 0;

//std::string rxValue; // Could also make this a global var to access it in loop()

// See the following for generating UUIDs:

// https://www.uuidgenerator.net/

#define SERVICE_UUID "6E400001-B5A3-F393-E0A9-E50E24DCCA9E" // UART service UUID

#define CHARACTERISTIC_UUID_RX "6E400002-B5A3-F393-E0A9-E50E24DCCA9E"

#define CHARACTERISTIC_UUID_TX "6E400003-B5A3-F393-E0A9-E50E24DCCA9E"

class MyServerCallbacks: public BLEServerCallbacks {

void onConnect(BLEServer* pServer) {

deviceConnected = true;

};

void onDisconnect(BLEServer* pServer) {

deviceConnected = false;

}

};

class MyCallbacks: public BLECharacteristicCallbacks {

void onWrite(BLECharacteristic *pCharacteristic) {

std::string rxValue = pCharacteristic->getValue();

if (rxValue.length() > 0) {

Serial.println("*********");

Serial.print("Received Value: ");

for (int i = 0; i < rxValue.length(); i++) {

Serial.print(rxValue[i]);

}

Serial.println();

// Do stuff based on the command received from the app

if (rxValue.find("SYS_ON") != -1) {

Serial.print("Turning ON!");

digitalWrite(RED, HIGH);

digitalWrite(BLUE, HIGH);

digitalWrite(GREEN, HIGH);

}

else if (rxValue.find("SYS_OFF") != -1) {

Serial.print("Turning OFF!");

digitalWrite(RED, LOW);

digitalWrite(BLUE, LOW);

digitalWrite(GREEN, LOW);

}

else if (rxValue.find("A") != -1) {

Serial.print("Turning ON!");

digitalWrite(BLUE, HIGH);

}

else if (rxValue.find("B") != -1) {

Serial.print("Turning OFF!");

digitalWrite(BLUE, LOW);

}

else if (rxValue.find("C") != -1) {

Serial.print("Turning ON!");

digitalWrite(RED, HIGH);

}

else if (rxValue.find("D") != -1) {

Serial.print("Turning OFF!");

digitalWrite(RED, LOW);

}

else if (rxValue.find("E") != -1) {

Serial.print("Turning ON!");

digitalWrite(GREEN, HIGH);

}

else if (rxValue.find("F") != -1) {

Serial.print("Turning OFF!");

digitalWrite(GREEN, LOW);

}

Serial.println();

Serial.println("*********");

}

}

};

void setup() {

Serial.begin(115200);

pinMode(RED, OUTPUT);

pinMode(GREEN, OUTPUT);

pinMode(BLUE, OUTPUT);

// Create the BLE Device

BLEDevice::init("ESP32"); // Give it a name

// Create the BLE Server

BLEServer *pServer = BLEDevice::createServer();

pServer->setCallbacks(new MyServerCallbacks());

// Create the BLE Service

BLEService *pService = pServer->createService(SERVICE_UUID);

// Create a BLE Characteristic

pCharacteristic = pService->createCharacteristic(

CHARACTERISTIC_UUID_TX,

BLECharacteristic::PROPERTY_NOTIFY

);

pCharacteristic->addDescriptor(new BLE2902());

BLECharacteristic *pCharacteristic = pService->createCharacteristic(

CHARACTERISTIC_UUID_RX,

BLECharacteristic::PROPERTY_WRITE

);

pCharacteristic->setCallbacks(new MyCallbacks());

// Start the service

pService->start();

// Start advertising

pServer->getAdvertising()->start();

Serial.println("Waiting a client connection to notify...");

}

void loop() {

if (deviceConnected) {

if(adder <= 10){

txValue = adder; // Test sensor reading

}

else{

adder = 0;

}

// Let's convert the value to a char array:

char txString[8];

dtostrf(txValue, 1, 2, txString); // float_val, min_width, digits_after_decimal, char_buffer

// pCharacteristic->setValue(&voltageValue, 1); // To send the integer value

pCharacteristic->setValue("120.0|1.23|2.45|3.40|00|05|45"); // Sending a test message

// pCharacteristic->setValue(txString);

pCharacteristic->notify(); // Send the value to the app!

Serial.print("*** Sent Value: ");

Serial.print(txString);

Serial.println(" ***");

}

adder += 1;

delay(1000);

}

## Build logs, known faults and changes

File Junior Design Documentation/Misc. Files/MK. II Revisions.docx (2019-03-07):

-Swap positive and negative terminals for XC60 connector - Fixed

-Resize footprint for ACS710_R_Sense - Fixed to be 1206 (3216)

-Resize relay footprint - Fixed

-Order stencil -

-Add QR Code, emails/contact info -

-Potentially change UART bridge -

-Potentially change Micro usb to B usb connector

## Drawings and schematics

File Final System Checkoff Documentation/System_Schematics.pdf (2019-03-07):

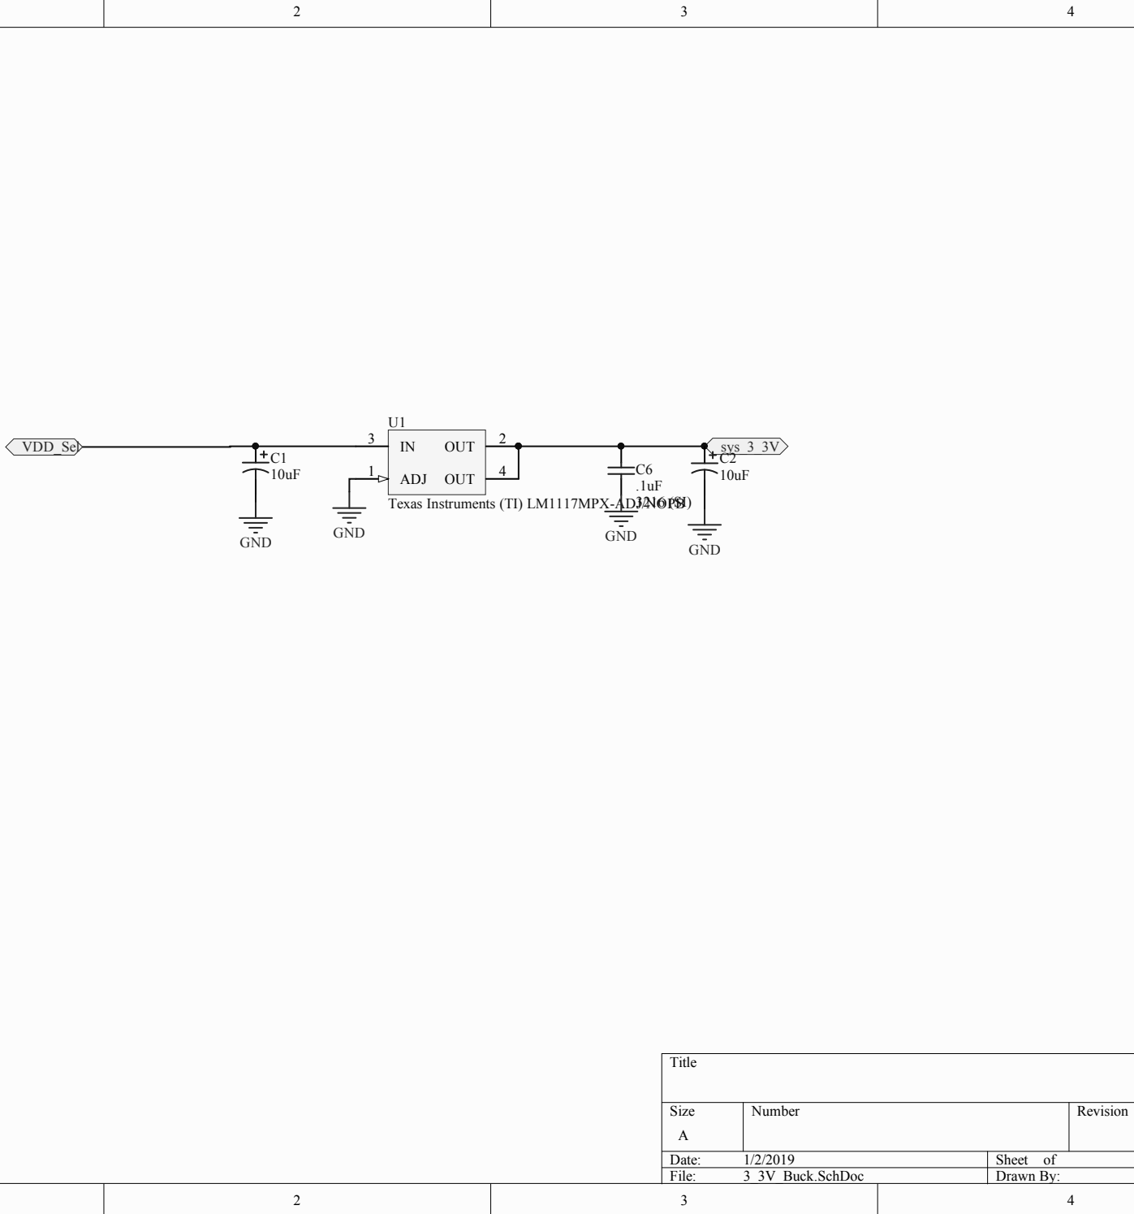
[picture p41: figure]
Numbe; Revi; ion; ADat; She e; 3_3V_Buck.; chDoc; Dra; exa; s Ins; trum; ent; sys_3_3V C1

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
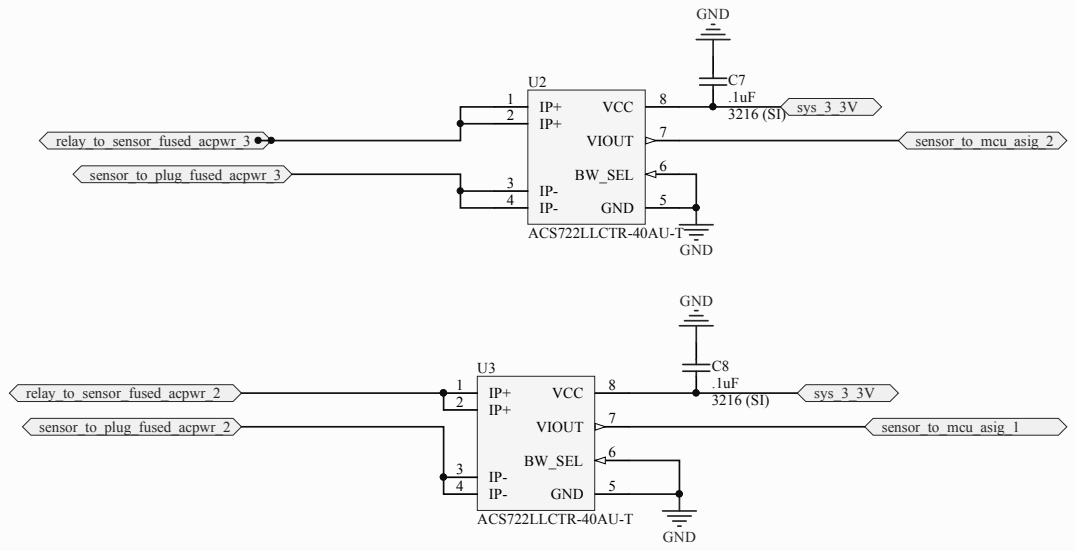
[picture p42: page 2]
Title; Size; Number; Revision; Date:; Sheet of; File:; Current_Sensors_ACS.SchDoc; Drawn By:; sensor_to_plug_fused_acpwr_2; relay_to_sensor_fused_acpwr_2; sys_3_3V; GND; relay_to_sensor_fused_acpwr_3; sensor_to_plug_fused_acpwr_3; sensor_to_mcu_asig_2; sensor_to_mcu_asig_1; VCC; VIOUT; BW_SEL; ACS722LLCTR-40AU-T

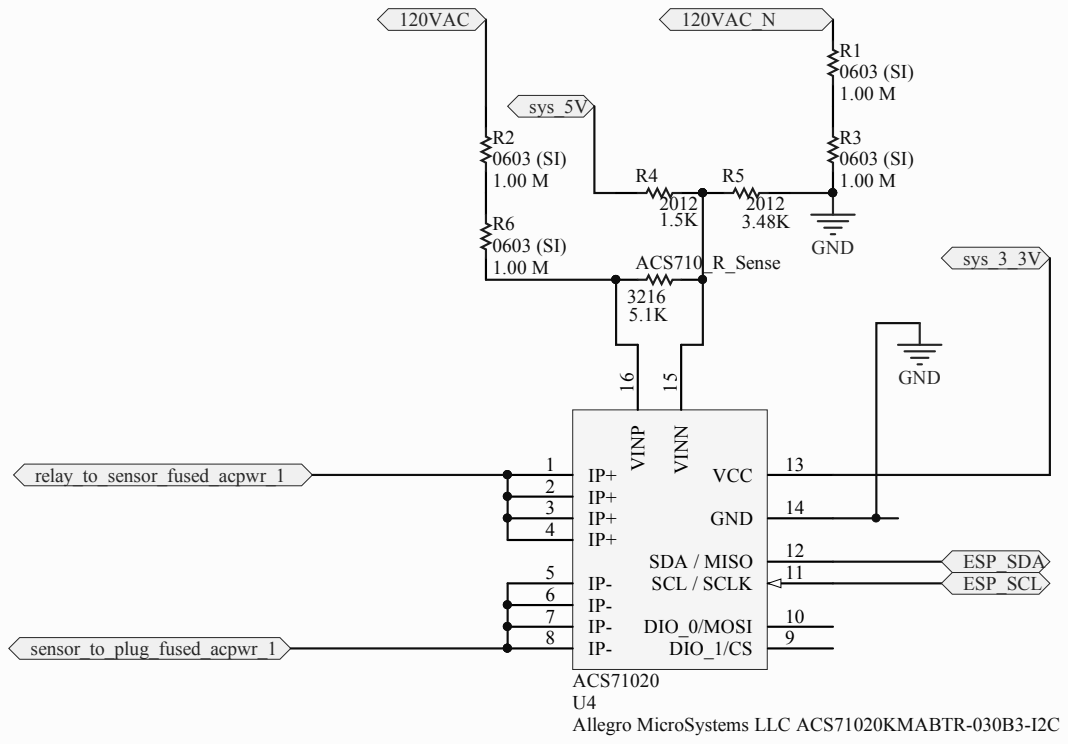
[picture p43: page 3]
Title; Size; Number; Revision; File:; Current_Voltage_Sensor_ACS.SchDoc; Drawn By:; DIO_1/CS; 9 DIO_0/MOSI; SCL / SCLK; 11 SDA / MISO; VCC; GND; VINN 15; VINP 16; ACS71020 U4 Allegro MicroSystems LLC ACS71020KMABTR-030B3-I2C; sys_3_3V; sensor_to_plug_fused_acpwr_1; relay_to_sensor_fused_acpwr_1; sys_5V; 120VAC; 120VAC_N; ESP_SDA ESP_SCL; ACS710_R_Sense

## COF1

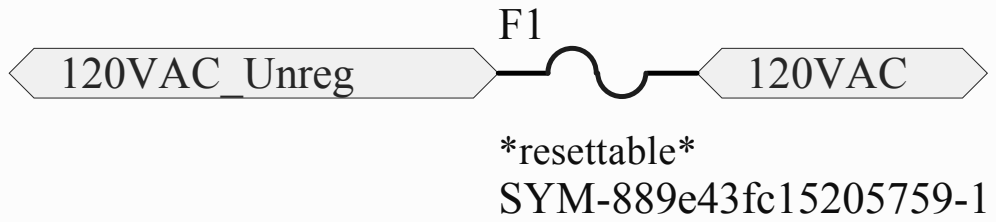
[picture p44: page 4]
Title; Size; Number; Revision; File:; Fuse.SchDoc; Drawn By:; 120VAC_Unreg; 120VAC; *resettable*; SYM-889e43fc15205759-1; PIF101; PIF102; PO120VAC0Unreg PO120VAC0UNREG; PO120VAC

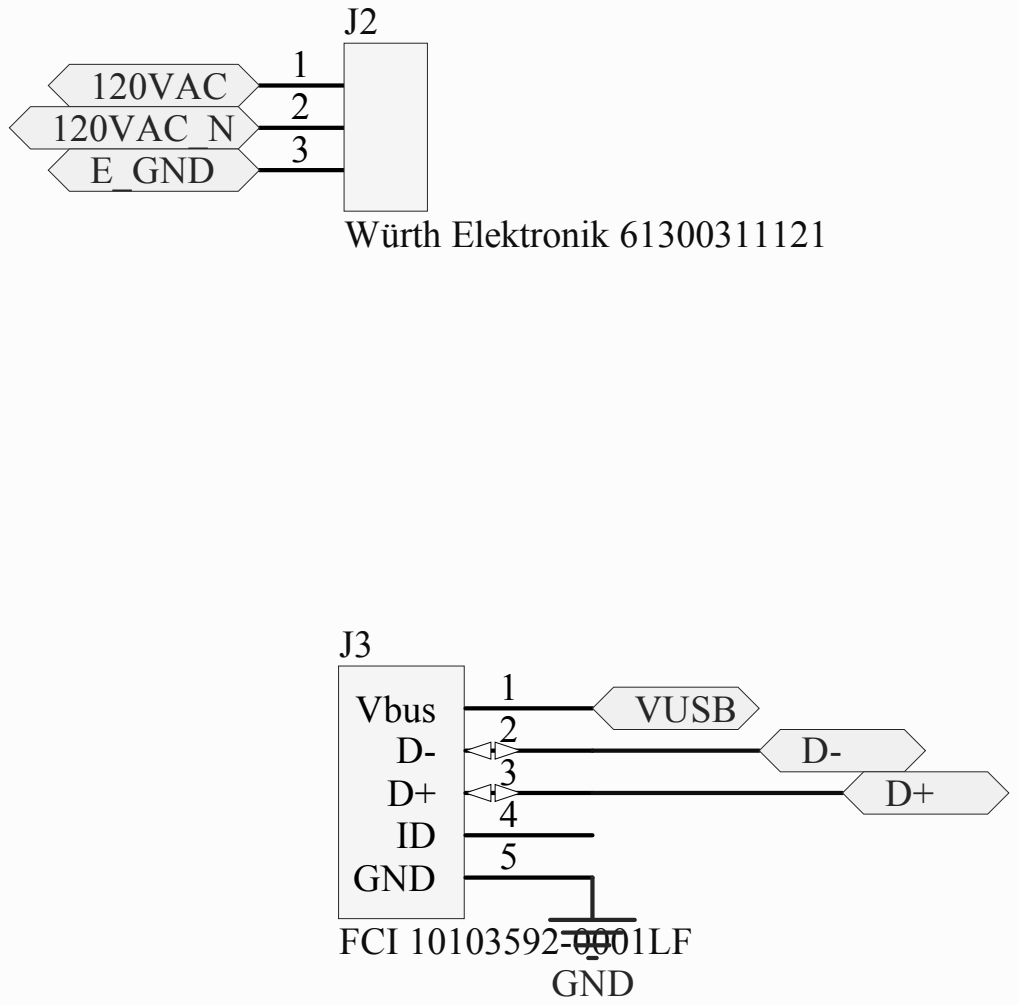
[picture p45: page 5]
Title; Size; Number; Revision; File:; Input_Plugs.SchDoc; Drawn By:; Vbus; GND; FCI 10103592-0001LF; VUSB; Würth Elektronik 61300311121; 120VAC 120VAC_N E_GND; PIJ201; PIJ202 PIJ203; COJ2; PIJ301; PIJ302 PIJ303 PIJ304 PIJ305; COJ3; PO120VACPIJ201 PO120VAC0NPIJ202; PIJ303; POD0; PIJ302; POE0GNDPIJ203; PIJ305; PIJ304; PIJ301POVUSB; PO120VAC PO120VAC0N; POE0GND

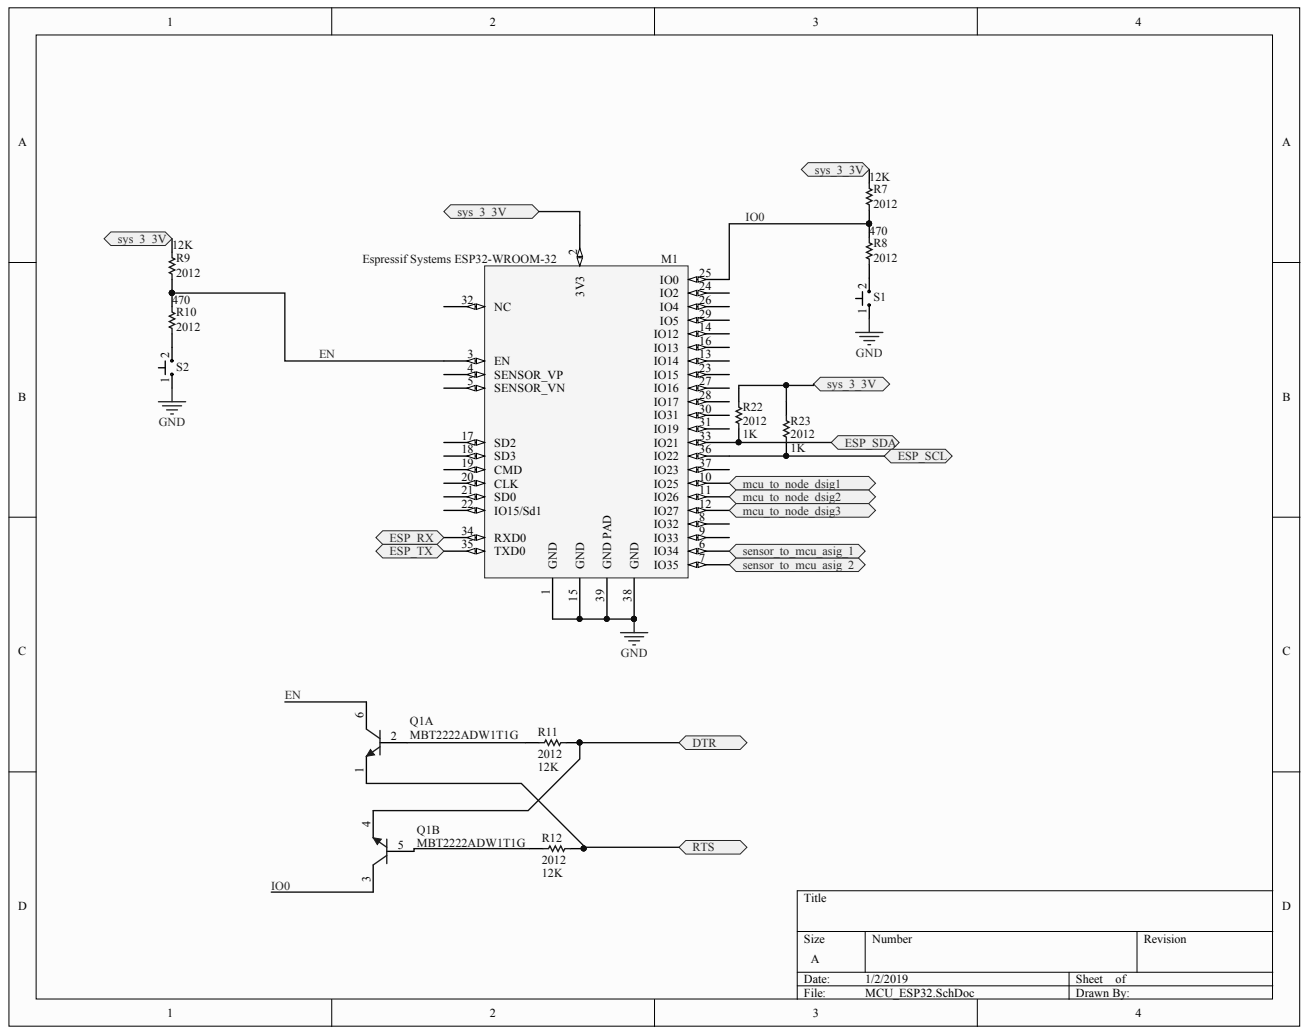
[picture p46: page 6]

## COJ4

POsensor0to0plug0fused0acpwr01 | PIJ40H

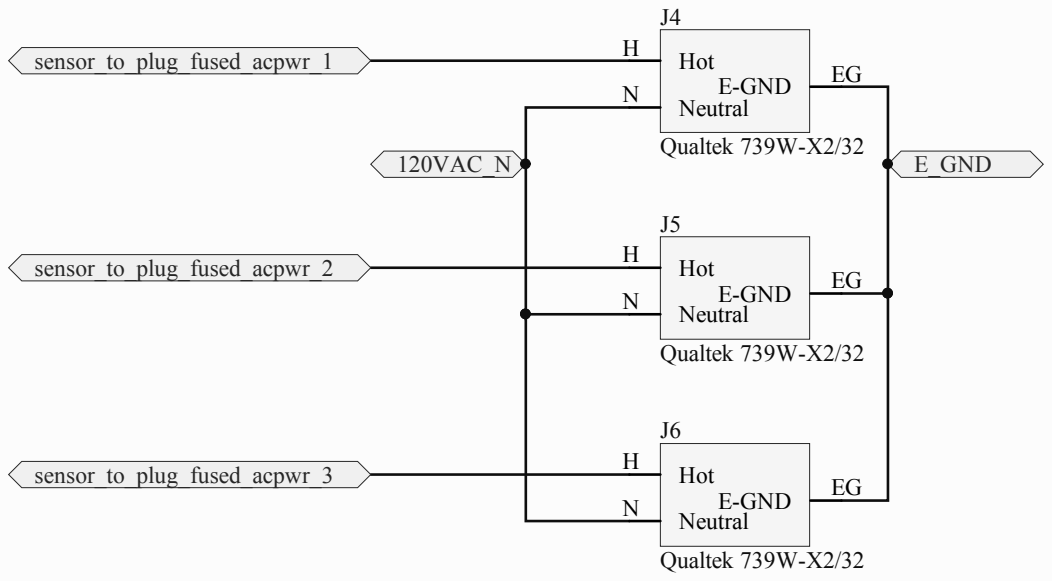
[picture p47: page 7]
Title; Size; Number; Revision; File:; Output_Plugs.SchDoc; Drawn By:; sensor_to_plug_fused_acpwr_1; sensor_to_plug_fused_acpwr_2; sensor_to_plug_fused_acpwr_3; 120VAC_N; E_GND; Hot H; Neutral N; E-GND; Qualtek 739W-X2/32; PIJ40EG; PIJ40H; PIJ40N; PIJ50EG; PIJ50H; PIJ50N; COJ5; PIJ60EG; PIJ60H; PIJ60N; COJ6; PO120VAC0N; POE0GND; POsensor0to0plug0fused0acpwr02; POsensor0to0plug0fused0acpwr03; POSENSOR0TO0PLUG0FUSED0ACPWR01; POSENSOR0TO0PLUG0FUSED0ACPWR02; POSENSOR0TO0PLUG0FUSED0ACPWR03

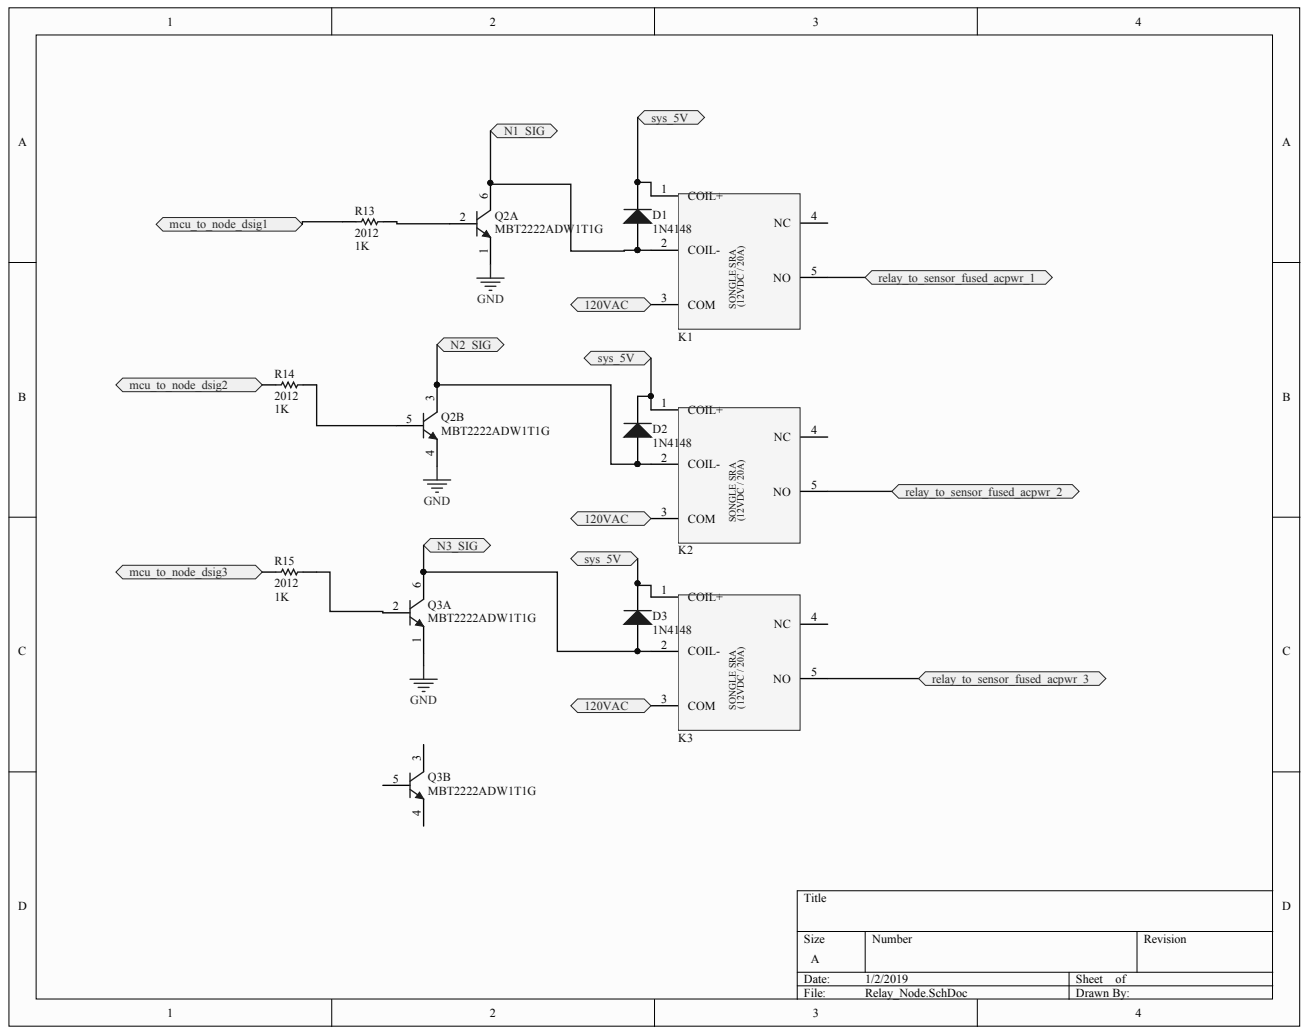
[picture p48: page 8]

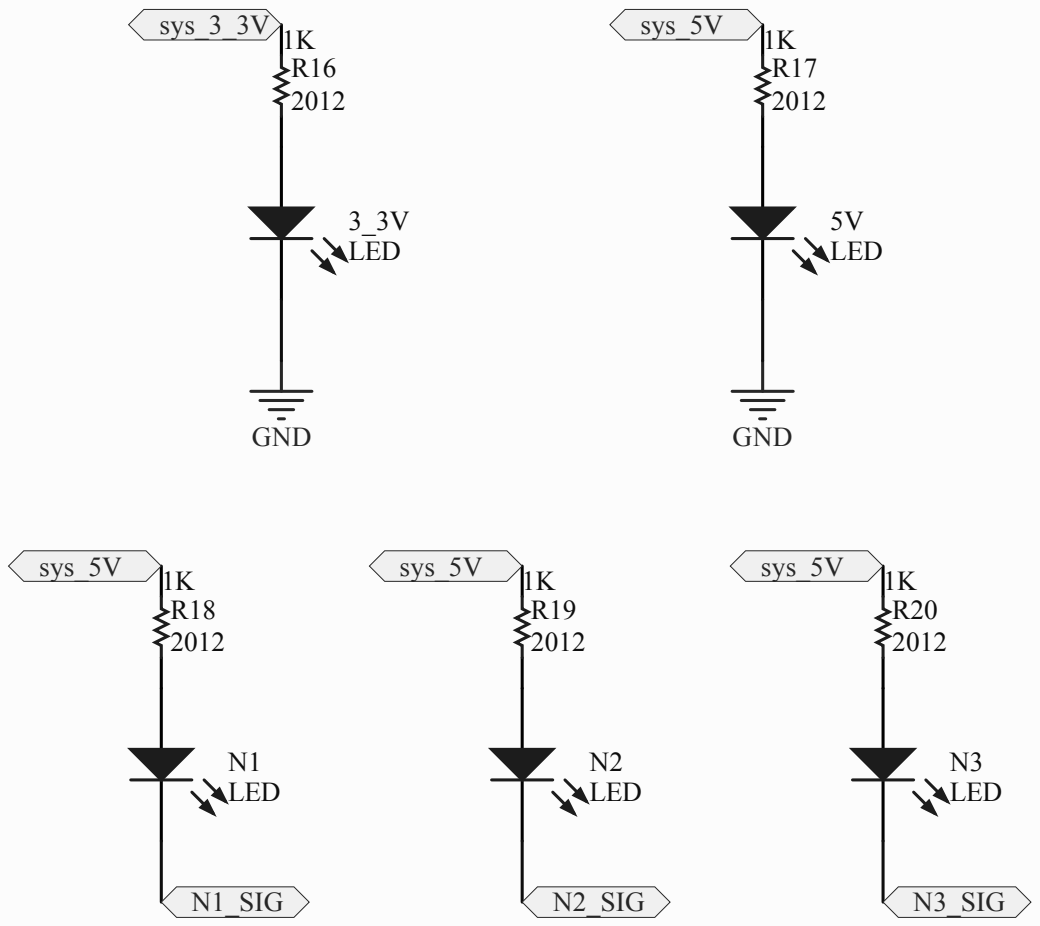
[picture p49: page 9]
Title; Size; Number; Revision; File:; Status_LEDs.SchDoc; Drawn By:; GND; sys_3_3V; 3_3V LED; sys_5V; 5V LED; N1 LED; N2 LED; N3 LED; N1_SIG; N2_SIG; N3_SIG

## COJ1

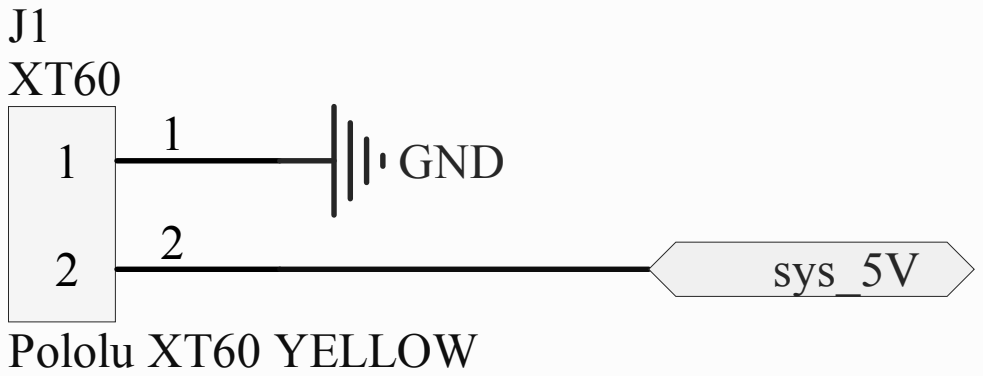
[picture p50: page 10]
Title; Size; Number; Revision; File:; Transformer.SchDoc; Drawn By:; Pololu XT60 YELLOW; GND; sys_5V; PIJ101; PIJ102; POsys05V POSYS05V

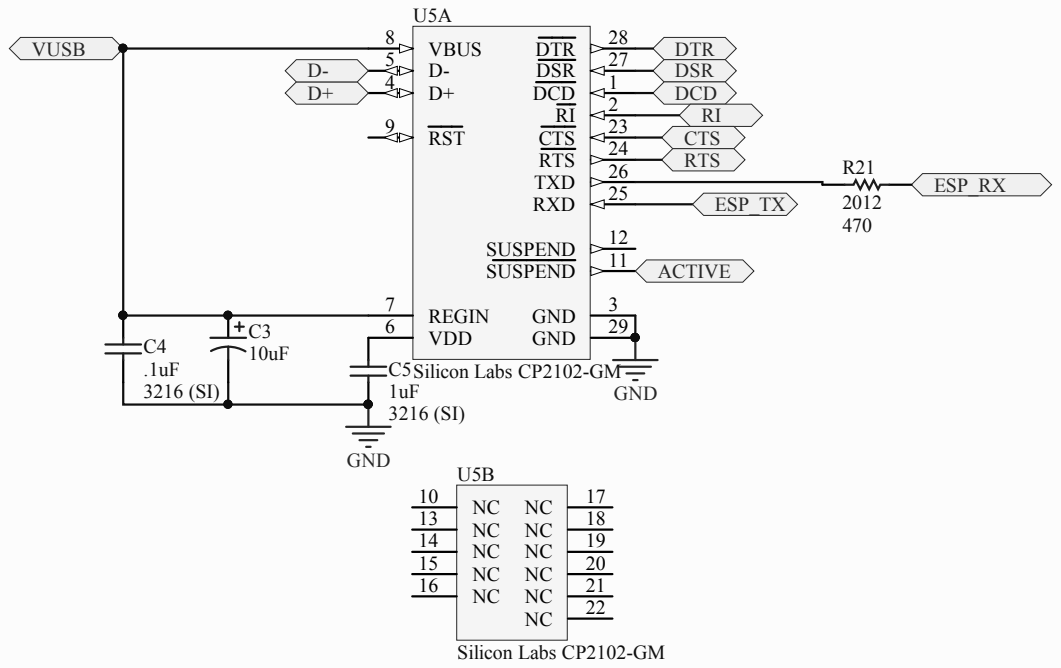
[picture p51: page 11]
Title; Size; Number; Revision; File:; UART_Bridge.SchDoc; Drawn By:; DCD; GND; VDD 6; REGIN 7; VBUS 8; RST 9; SUSPEND; 11 SUSPEND; CTS; RTS; RXD; 25 TXD; DSR; 27 DTR; DTR DSR DCD RI CTS RTS; ACTIVE; ESP_TX; VUSB; ESP_RX

Silicon Labs CP2102-GM

## COD4

## COD5

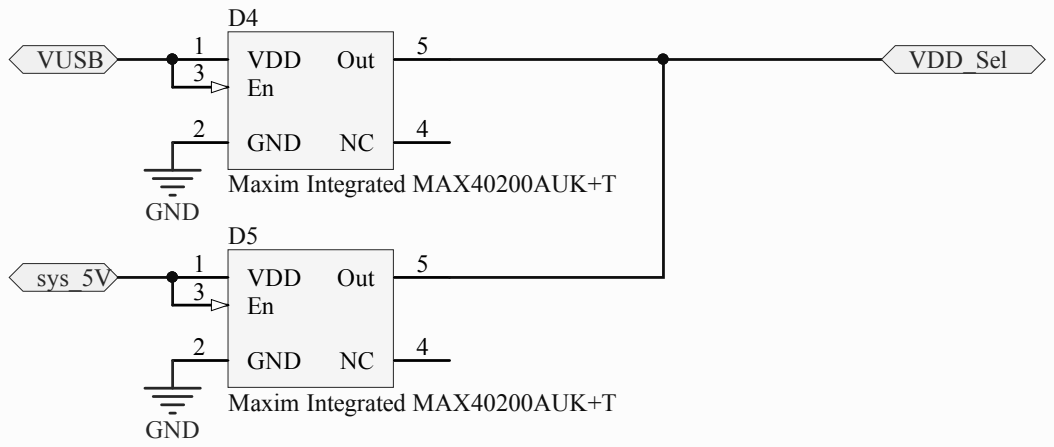
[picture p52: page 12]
Title; Size; Number; Revision; File:; Voltage_Selector.SchDoc; Drawn By:; 4 GND 2; Out; VDD 1; Maxim Integrated MAX40200AUK+T; VUSB; VDD_Sel; sys_5V; GND; PID401; PID402; PID403; PID404; PID405; PID501; PID502; PID503; PID504; PID505; POsys05V; POVDD0Sel PID403; POVUSB; POSYS05V; POVDD0SEL

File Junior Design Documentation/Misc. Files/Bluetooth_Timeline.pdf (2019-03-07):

Resettable Fuse Abandoned; 0 days; Thu 1/24/19; 1st Case Revisions; 2nd Case Revisions 2/10; February 2019; March 2019; Task; Split; Milestone; Summary; Project Summary; Inactive Task; Inactive Milestone; Inactive Summary; Start-only; Finish-only; External Tasks; External Milestone; Deadline; Progress; Manual Progress; Page 1; Project: Bluetooth_Timeline Date: Tue 2/26/19

ID | Task Mode | Task Name | Duration | Start | Finish | Predecessors | Resource Names
1 | | 1st PCB Revision Arrived | 0 days | Tue 1/15/19 | Tue 1/15/19 | | | 2nd Revision PCB Component Mounting and Testing | Wi-Fi Capabilities Smartphone App

1st PCB Revision Arrived

2 | | 1st Revision PCB Testing | 6 days | Thu 1/17/19 | Thu 1/24/19

1st Revision PCB Testing

3 | | Proof of Concept Working | 0 days | Thu 1/24/19 | Thu 1/24/19

Proof of Concept Working

4 | | Wi-Fi Capabilities | 26 days | Fri 1/25/19 | Fri 3/1/19 | 2

5 | | Wi-Fi Connection Established | 0 days | Mon 2/25/19 | Mon 2/25/19

Wi-Fi Connection Established

6 | | Smartphone App | 28 days | Fri 1/25/19 | Tue 3/5/19 | 2

7 2nd Revision PCB Component | | Mounting and Testing | 15 days | Mon 1/28/19 | Fri 2/15/19 | 2

Resettable Fuse Abandoned

9 | 2nd Revision PCB Arrived | 0 days | Mon 1/28/19 | Mon 1/28/19

2nd Revision PCB Arrived

10 | Transformer Wired In | 0 days | Thu 2/21/19 | Thu 2/21/19

Transformer Wired In

11 | Serial Power Sensing Code | 21 days | Sun 2/3/19 | Fri 3/1/19 | 7

12 | Serial Voltage Sensing Finalized | 0 days | Mon 2/25/19 | Mon 2/25/19

Serial Voltage Sensing Finalized

13 | Analog Current Sensing Code | 6 days | Thu 1/31/19 | Thu 2/7/19 | 7

14 | 1st Case Revisions | 7 days | Thu 1/24/19 | Fri 2/1/19

15 | 2nd Case Revisions | 11 days | Thu 2/7/19 | Thu 2/21/19 | 14

16 | USB Ports Added to Case | 0 days | Sun 2/10/19 | Sun 2/10/19

USB Ports Added to Case

17 | Final Case Revision Emerges | 0 days | Thu 2/21/19 | Thu 2/21/19

Final Case Revision Emerges

Manual Task
Duration-only
Manual Summary Rollup
Manual Summary

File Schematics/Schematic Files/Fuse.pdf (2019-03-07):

## COF1

Title; Size; Number; Revision; Date:; Sheet of; File:; Fuse.SchDoc; Drawn By:; 120VAC_Unreg; 120VAC; *resettable*; SYM-889e43fc15205759-1; PIF101; PIF102; PO120VAC0Unreg PO120VAC0UNREG; PO120VAC

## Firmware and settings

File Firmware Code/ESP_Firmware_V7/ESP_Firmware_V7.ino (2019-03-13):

#include <BLEDevice.h>
#include <BLEServer.h>
#include <BLEUtils.h>
#include <BLE2902.h>


#include <WiFi.h>
#include <PubSubClient.h>

#include <Wire.h>
//#include "Countimer.h"
/************************************************
 * Bluetooth Stuff
 */
bool deviceConnected = false;
int TxCounter = 0;
int relay_3 = 18; //Pin to set relay 3 state (see above) 
int relay_1 = 25; //Pin to set relay 1 state (off = HIGH, on = LOW)
int relay_2 = 26; //Pin to set relay 2 state (see above)

/*Bluetooth stuff
 */

#define SENSORS_SERVICE_UUID "6E400034-B5A3-F393-E0A9-E50E24DCCA9E" // UART service UUID
#define RX_UUID "6E400035-B5A3-F393-E0A9-E50E24DCCA9E"
BLECharacteristic* RxCharacteristic;
#define TX_UUID "6E400036-B5A3-F393-E0A9-E50E24DCCA9E"
BLECharacteristic* TxCharacteristic;


class MyServerCallbacks: public BLEServerCallbacks {
    void onConnect(BLEServer* pServer) {
      deviceConnected = true;
    };

    void onDisconnect(BLEServer* pServer) {
      deviceConnected = false;
    }
};


/************************************************
 * Wifi Control Stuff
 */
 
const char* ssid = "billnyethewifi";
const char* password = "Robot123";

const char* mqtt_server = "192.168.8.101"; //Set ip of MQTT broker 

WiFiClient espClient;  //Initalize Wifi object
PubSubClient client(espClient); //Use wifi object to setup MQTT client
long lastMsg = 0; //Store flag about last message recieved
char msg[50]; //array to store message received
String Data; 
long lastReconnectAttempt = 0;

/************************************************
 * General Stuff
 */
//Countimer plug_one;  //Countdown timer for plug one
//Countimer plug_two;   //Countdown timer for plug two
//Countimer plug_three; //Countdown timer for plug three

int plug_one = 0;
int plug_two = 0;
int plug_three = 0;
int time_one = 0;
int time_two = 0;
int time_three = 0;

int csns_2 = 34; //Pin to read current data from plug 2
int csns_3 = 35; //Pin to read current data from plug 1

float cur_1 = 0;
float cur_2 = 0;


#define SENSOR 0x61                          // DO NOT CHANGE | Slave address of current/voltage sensor (ACS71020)

const int numReadings_1 = 10;                 // number of elements in shift register

float readings[numReadings_1];                // shift register that holds last n current readings, where n = numReadings
float total = 0;                            // the total of currents in shift register
float average = 0;                          // the average of last n current readings, where n = numReadings
float current_1 = 0.0;                        // calculated current from sensor
int inputVal = 0;                           // raw input from sensor
int bias = 0;                               // input from sensor adjusted for zero-current bias

const int numReadings_2 = 10;                 // number of elements in shift register

float readings_2[numReadings_2];                // shift register that holds last n current readings, where n = numReadings
float total_2 = 0;                            // the total of currents in shift register
float average_2 = 0;                          // the average of last n current readings, where n = numReadings
float current_2 = 0.0;                        // calculated current from sensor
int inputVal_2 = 0;                           // raw input from sensor
int bias_2 = 0;                               // input from sensor adjusted for zero-current bias

const int numReadings = 175;                 // number of elements in shift register for "relative" average

uint8_t inputs[4];                           // stores input from chip | index 0 and 1 are voltage, 2 and 3 are current
String bits[4];                              // literal binary representation of inputs
String voltage = "0000000000000000";         // holds 16 voltage bits 
String current = "0000000000000000";         // holds 16 current bits
float cur_readings[numReadings];             // shift register that holds last n current readings, where n = numReadings
float vol_readings[numReadings];             // shift register that holds last n voltage readings, where n = numReadings
float final_voltage = 0;                     // float form of binary voltage bits
float final_current = 0;                     // float form of binary current bits
float max_vol = 0;                           // biased and scaled voltage
float max_cur = 0;                           // biased and scaled current

#define SENSOR_BIAS_ALPHA 1850                                // zero current bias for 1st current sensor
#define SENSOR_BIAS_BRAVO 1850                                // zero current bias for 2nd current sensor

const int num_readings_too = 25;                           // number of elements in shift register
const int input_pin_alpha = 34;                               // input pin for 1st channel of microcontroller
const int input_pin_bravo = 35;                                // input pin for 2nd channel of microcontroller

float readings_alpha[num_readings_too];                           // shift register that holds last n current readings for sensor 1, where n = num_readings_too
float readings_bravo[num_readings_too];                            // shift register that holds last n current readings for sensor 2, where n = num_readings_too
float current_alpha = 0.0;
float current_bravo = 0.0;                                          // calculated current from sensors
float max_val_1 = 0;
float max_val_2 = 0;
int inputVal_alpha = 0;                                             // raw input from sensors
int inputVal_bravo = 0;
int bias_alpha = 0;                                                 // input from sensors adjusted for zero-current bias
int bias_bravo = 0;

long stop_time = 0;

String voltagePkg = "";
String current1Pkg = "";
String current2Pkg = "";
String current3Pkg = "";
String Timer1Pkg = "";
String Timer2Pkg = "";
String Timer3Pkg = "";


//Handles when signal is received by the app
class RxCallbacks: public BLECharacteristicCallbacks {
    void onWrite(BLECharacteristic *RxCharacteristic) {
      std::string rxValue = RxCharacteristic->getValue();

      if (rxValue.length() > 0) {
        // Do stuff based on the signal received from the app
        
        if (rxValue.find("A") != -1) { 
          Serial.print("TURN ON 1");
          plug_one = 3.6*pow(10,6);
        }
        else if (rxValue.find("B") != -1) {
          Serial.print("TURN OFF 1");
          plug_one = 0;
        }
        
        if (rxValue.find("C") != -1) {
          Serial.print("TURN ON 2"); 
          plug_two = 3.6*pow(10,6);
        }
        else if (rxValue.find("D") != -1) {
          Serial.print("TURN OFF 2");
          plug_two = 0;
        }
        
        if (rxValue.find("E") != -1) {
          Serial.print("TURN ON 3"); 
          plug_three = 3.6*pow(10,6);
        }
        else if (rxValue.find("F") != -1) {
          Serial.print("TURN OFF 3");
          plug_three = 0;
        }
        //Serial.println();
        //Serial.println("*********");
      }
      start_timers();
    }
    
};

void InitalizeBLE(){
  // Create the BLE Device
  BLEDevice::init("THIS-IS-A-PLUG"); // Give it a name

  // Create the BLE Server
  BLEServer *Server = BLEDevice::createServer();
  Server->setCallbacks(new MyServerCallbacks());

  // Create the BLE Service
  BLEService *Service = Server->createService(SENSORS_SERVICE_UUID);

  // Setup BLE Characteristics
  RxCharacteristic = Service->createCharacteristic(RX_UUID, BLECharacteristic::PROPERTY_WRITE);
  TxCharacteristic = Service->createCharacteristic(TX_UUID, BLECharacteristic::PROPERTY_NOTIFY);
  

  // Start the service
  Service->start();

  // Start advertising
  Server->getAdvertising()->start();
  Serial.println("Waiting a client connection to notify...");
}

void setup() {
  Serial.begin(9600);
  
  InitalizeBLE();
  
  // put your setup code here, to run once:
  Wire.begin();
  Wire.setClock(400000);                     // set clock rate [400kHz is max for ASC71020]
  pinMode(csns_2, INPUT);
  pinMode(csns_3, INPUT);

  pinMode(relay_1, OUTPUT);
  pinMode(relay_2, OUTPUT);
  pinMode(relay_3, OUTPUT);
    
  for (int i = 0; i < num_readings_too; i++) {                    // initialize all readings to 0
    readings_alpha[i] = 0;                        
    readings_bravo[i] = 0;
  } 
  
  for (int i = 0; i < numReadings; i++) {    // initialize all readings to 0
    vol_readings[i] = 0;
    cur_readings[i] = 0;                        
  }  
  /*
   * Structure for the below class call is as follows: starting Hour, minute, second, 
   * object behavior (count up or down), and what function to call when timer is done 
   * (with any specific arguments)
   */
  //plug_three.setCounter(0,0,0,plug_three.COUNT_DOWN,timer_complete_3);
  //plug_one.setCounter(0,0,0,plug_one.COUNT_DOWN,timer_complete_1); 
  //plug_two.setCounter(0,0,0,plug_two.COUNT_DOWN,timer_complete_2);


  setup_wifi();
  client.setServer(mqtt_server, 1883);
  client.setCallback(callback);

}
/*
 * Basically just a monitor function, will check for any changes in the system and
 * call specific functions accordingly. 
 * Inputs: none
 * Outputs: none
 * Behavior: The only things that aren't on inturrupts are the current sensing, voltage
 * sensing, and heartbeat message. This function should contiuously measure the current
 * and voltage, and then send out a heartbeat message to the MQTT broker/Bluetooth device
 * (if connected) with data about the voltage, current for each plug, timer statuses
 * and any issues (flags in the system). 
 */
void loop() {
 
  //plug_one.run();
  //plug_two.run();
  //plug_three.run();
  check_time();
  get_sensor();
  Data = String("!|") + max_vol + String("|") + max_cur + String("|") + A_current_1() + String("|") + A_current_2() + String("|") 
  + get_time(time_one, plug_one) + String("|") + get_time(time_two, plug_two) + String("|")+ get_time(time_three, plug_three) + String("|?");  //Append all the data to one string
//  Serial.println(Data);
  voltagePkg = String("|V|") + String(max_vol) + String("|");
  current1Pkg = String("|C1|") + String(max_cur + String("|"));
  current2Pkg = String("|C2|") + String(A_current_1()) + String("|");
  current3Pkg = String("|C3|") + String(A_current_2()) + String("|");
  Timer1Pkg = String("|T1|") + String(get_time(time_one, plug_one)) + String("|");
  Timer2Pkg = String("|T2|") + String(get_time(time_two, plug_two)) + String("|");
  Timer3Pkg = String("|T3|") + String(get_time(time_three, plug_three)) + String("|");

    if(TxCounter == 16){
      TxCounter = 0;
    }
    
    if(TxCounter == 0){
    TxCharacteristic->setValue(voltagePkg.c_str());
    //Serial.println(voltagePkg);
    }

    else if(TxCounter == 1){
    TxCharacteristic->setValue(Timer1Pkg.c_str());
    //Serial.println(Timer1Pkg);
    }

    else if(TxCounter == 2){
    TxCharacteristic->setValue(Timer2Pkg.c_str());
    //Serial.println(Timer2Pkg);
    }

    else if(TxCounter == 3){
    TxCharacteristic->setValue(Timer3Pkg.c_str());
    //Serial.println(Timer3Pkg);
    }
    
    else if(TxCounter == 4){
    TxCharacteristic->setValue(current1Pkg.c_str());
    //Serial.println(current1Pkg);
    }

    else if(TxCounter == 5){
    TxCharacteristic->setValue(Timer1Pkg.c_str());
    //Serial.println(Timer1Pkg);
    }

    else if(TxCounter == 6){
    TxCharacteristic->setValue(Timer2Pkg.c_str());
    //Serial.println(Timer2Pkg);
    }

    else if(TxCounter == 7){
    TxCharacteristic->setValue(Timer3Pkg.c_str());
    //Serial.println(Timer3Pkg);
    }

    else if(TxCounter == 8){
    TxCharacteristic->setValue(current2Pkg.c_str());
    //Serial.println(current2Pkg);
    }

    else if(TxCounter == 9){
    TxCharacteristic->setValue(Timer1Pkg.c_str());
    //Serial.println(Timer1Pkg);
    }

    else if(TxCounter == 10){
    TxCharacteristic->setValue(Timer2Pkg.c_str());
    //Serial.println(Timer2Pkg);
    }

    else if(TxCounter == 11){
    TxCharacteristic->setValue(Timer3Pkg.c_str());
    //Serial.println(Timer3Pkg);
    }

    else if(TxCounter == 12){
    TxCharacteristic->setValue(current3Pkg.c_str());
    //Serial.println(current3Pkg);
    }

    else if(TxCounter == 13){
    TxCharacteristic->setValue(Timer1Pkg.c_str());
    //Serial.println(Timer1Pkg);
    }

    else if(TxCounter == 14){
    TxCharacteristic->setValue(Timer2Pkg.c_str());
    //Serial.println(Timer2Pkg);
    }

    else if(TxCounter == 15){
    TxCharacteristic->setValue(Timer3Pkg.c_str());
    //Serial.println(Timer3Pkg);
    }

    TxCharacteristic->notify();
    TxCounter++;

     if (!client.connected()) { //Checks if we're connected to an MQTT broker, if not try
      long now = millis();
      if (now - lastReconnectAttempt > 5000) {
        lastReconnectAttempt = now;
        // Attempt to reconnect
        if (reconnect()) {
          lastReconnectAttempt = 0; //Keep track of how long we've spend trying (will attempt every >=5 sec) 
        }
      }
    }
    else { 
      // Client connected
        if(client.connected()) //only publish if we're actually connected
        {
       client.publish("/Switch/Data", Data.c_str()); //Publish heartbeat of data        
            //}
        }
      client.loop();
    }
    delay(500);
}


void check_time()
{
  if(millis() - time_one > plug_one)
  {
    timer_complete_1();
  }
  if(millis() - time_two > plug_two)
  {
    timer_complete_2();
  }
  if(millis() - time_three > plug_three)
  {
    timer_complete_3();
  }
}

String get_time(int time_to, int plug)
{
  time_to = plug - (millis() - time_to); 
  if(time_to <= 0)
  {
    return "00:00:00";
  }
  String format = "";
  int hours = time_to/(3.6*pow(10,6));
  time_to = time_to - hours*3.6*pow(10,6); 
  if(hours < 10)
  {
    format = "0" + String(hours) + ":"; 
  }
  else
  {
    format = String(hours) + ":";
  }
  int minutes = time_to/60000;
  time_to = time_to - minutes*60000;
  if(minutes < 10)
  {
    format = format + "0" + String(minutes) + ":"; 
  }
  else
  {
    format = format + String(minutes) + ":";
  }
  int seconds = time_to/1000;
  if(seconds < 10)
  {
    format = format + "0" + String(seconds);
  }
  else
  {
    format = format + String(seconds);
  }
  return format;
}
/*
 * What to do when the timer is done counting down. 
 * Inputs: none
 * Outputs: none
 * Behavior: Will check which timer expirelay_2 and set that timer's respective plug to OFF. Had to make 3 
 * seperate functions because the timer will reset back to it's max value once complete (which would be unknown). So 
 * by making 3 functions, whichever one gets called, we'll know exactly which timer completed
 */
void timer_complete_1()
{
  digitalWrite(relay_1, HIGH);
  plug_one = 0;
}

void timer_complete_2()
{
  digitalWrite(relay_2, HIGH);
  plug_two = 0;
}

void timer_complete_3()
{
  digitalWrite(relay_3, HIGH);
  plug_three = 0;
}

/*
 * Funciton to connect to a WIFI signal 
 * Inputs: none (global variables should be setup before: ssid, password
 * Outputs: none
 * Behavior: Will attempt to connect to a WIFI signal using the wifi.h library. Will try for 
 */
void setup_wifi() {

  delay(10);
  // We start by connecting to a WiFi network
  //Serial.println();
  //Serial.print("Connecting to ");
  //Serial.println(ssid);

  WiFi.begin(ssid, password);

  while (WiFi.status() != WL_CONNECTED) {
    delay(500);
    //Serial.print(".");
  }

  randomSeed(micros());

  //Serial.println("");
  //Serial.println("WiFi connected");
  //Serial.println("IP address: ");
  //Serial.println(WiFi.localIP());
}

/*
 * The action taken when a message is recieved
 * Inputs: The topic that the message is apart of (char array), the payload delievered (byte array), and how long the payload is (int)
 * Outputs: none
 * Behavior: This function will parse a standard message that should be sent from the webclient/broker. It should take the form of !|Timer1|Timer2|Timer3|? where the timers are all
 * formatted as HH:MM:SS (HH, MM, and SS should all be bytes with the numbers as chars) 
 */



void start_timers()
{
  if(plug_one != 0)
  {
    digitalWrite(relay_1, LOW);
    time_one = millis();
  }
    if(plug_two != 0)
  {
    digitalWrite(relay_2, LOW);
    time_two = millis();
  }
    if(plug_three != 0)
  { 
    digitalWrite(relay_3, LOW);
    time_three = millis();
  }
}

void callback(char* topic, byte* payload, unsigned int length) {
  if(length == 30)
  {
    for(int i = 2; i < 28; i++)
    {
       payload[i] = payload[i] - 48;
    }
    if(payload[0] == '!' && payload[29] == '?') //error checking to make sure message is properly formatted
    {
     plug_one = ((payload[2]*10 + payload[3])*3.6*(pow(10,6))) + ((payload[5]*10 + payload[6])*60000) + ((payload[8]*10 + payload[9])*1000); //Selectively take out the values needed 
     plug_two = ((payload[11]*10 + payload[12])*3.6*(pow(10,6)))+ ((payload[14]*10 + payload[15])*60000) + ((payload[17]*10 + payload[18])*1000); //Selectively take out the values needed
     plug_three = ((payload[20]*10 + payload[21])*3.6*(pow(10,6))) + ((payload[23]*10 + payload[24])*60000) + ((payload[26]*10 + payload[27])*1000); //Selectively take out the values needed
     start_timers();
    }
  }
}
/*
 * Simple function to reconnect the client to the broker
 * Inputs: none
 * Outputs: Boolean, if connected (TRUE) or not (FALSE)
 * Behavior: Will try to connect to the specified broker. If able to, will publish an opening statement in the /Init/ topic
 */

boolean reconnect() {
  if (client.connect("BTSwitch")) { //What it will be called to the broker
    // Once connected, publish an announcement...
    client.publish("Init","hello world"); //Opening statement on topic /Init/ with message
    // ... and resubscribe
    client.subscribe("Commands"); //Subscribe to this specific topic for messages from the web-client
  }
  return client.connected(); //Return if connected or not
}

String toBinary(const uint8_t dec){             // returns literal binary equivalent string of decimal input
  int counter = 0;                              // tracks position of bitmask
  String temp = "00000000";                     // 8 bit container to hold binary result

  for(uint8_t i = 0x80; i != 0; i >>= 1){       // applies shifting bitmask and stores result to temp string
    temp[counter] = (dec & i) ? '1' : '0';      // if (dec & i) != 0, then temp[counter] = 1, else temp[counter] = 0
    counter++;                                  // increments position of bitmask tracker  
  }
  return temp;                                  // final result is 8-char string of literal binary representation of input decimal Ex: 23 --> 00010111
}
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

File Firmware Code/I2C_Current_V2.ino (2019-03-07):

// Note: 0x20 register holds current and voltage for ASC71020 current sensor
// first 15 bits hold rms voltage value, and next 15 bits hold rms current value

#include <Wire.h>                            // utilizes Arduino Wire library

#define SENSOR 0x61                          // DO NOT CHANGE | Slave address of current/voltage sensor

uint8_t inputs[4];                           // inputs[0] = data7_0, inputs[1] = data15_8, inputs[2] = data23_16, inputs[3] = data31_24
String bits[4];                              // literal binary representation of inputs
String memory_map = "";                      // concatination of literal binary representation of inputs == [data31_24 + data23_16 + data15_8 + data7_0]                   
String voltage = "000000000000000";          // holds 15 voltage bits
String current = "000000000000000";          // holds 15 current bits
float final_voltage = 0;                     // final calculated and scaled voltage
float final_current = 0;                     // final calculated and scaled current
 
void setup() {
  Wire.begin();                              // no address == join as master
  Wire.setClock(400000);                     // set clock rate [400kHz is max for ASC71020]
  Serial.begin(115200);                      // initialize serial communication with computer
}

void loop() {
  Wire.beginTransmission(SENSOR);            // write start signal + slave address + write bit
  Wire.write(0x20);                          // write desired register
  Wire.endTransmission();                    // send singal + write new start signal
  Wire.requestFrom(SENSOR, 4);               // write slave address + read bit (request 4 bytes)
  
  while(Wire.available()){                        // Wire.available() returns number of bytes left to send from slave
    inputs[4 - Wire.available()] = Wire.read();   // read from slave     
  }                                               // inputs[0] = data7_0, inputs[1] = data15_8, inputs[2] = data23_16, inputs[3] = data31_24

  for (int i = 0; i < 4; i++){  
    bits[i] = toBinary(inputs[i]);                // convert int to binary
  }

  Wire.endTransmission(1);                        // stop signal

  for (int j = 3; j >= 0; j--){                   // concatinate inputs into "memory map"
    memory_map += bits[j];
  }

  for (int k = 0; k < 15; k++){                                                           // convert binary to readable, calibrated float values
    current[k] = memory_map[1 + k];                                                       // pluck current reading from memory map
    voltage[k] = memory_map[17 + k];                                                      // pluck voltage reading from voltage map
    final_current += float(int((current[k] - '0'))) * float(pow(2.0, float(-(k+1))));     // find current decimal value sent by sensor
    final_voltage += float(int((voltage[k] - '0'))) * float(pow(2.0, float(-(k+1))));     // find voltage decimal value sent by sensor
                                                                                          // convert char -> int -> float then multiply bit by 2^-(decimal place) to find value to add to decimal
                                                                                          // look up Q decimal binary format for reference
  }

  final_current *= 30.0;                                                                  // scale current 
  final_voltage *= 215.5;                                                                 // scale voltage

  debug(memory_map, voltage, current, final_voltage, final_current, inputs);              // print values to serial plotter
  reset(memory_map, final_voltage, final_current, voltage, current, inputs, bits);        // reset values for next loop
  
  delay(100);                                                                             // delay for stability
}

void debug(const String mem, const String vol, const String cur, const float f_vol, const float f_cur, const uint8_t inputs[4]){
  for (int i = 0; i < 4; i++){                                                                    
      Serial.print("byte ["); Serial.print(i); Serial.print("] dec: "); Serial.print(inputs[i]); Serial.print(" | bin: "); Serial.println(toBinary(inputs[i]));   
  }                                                                                               // print each transmitted byte from sensor
  
  Serial.print("memory: "); Serial.println(mem);                                                  // print memory map
  Serial.print("voltage bits: "); Serial.println(vol);                                            // print equiv. voltage bits
  Serial.print("current bits: "); Serial.println(cur);                                            // print equiv. current bits
  Serial.print("calculated voltage: "); Serial.print(f_vol); Serial.println(" volts");            // print calc. voltage value
  Serial.print("calculated current: "); Serial.print(f_cur); Serial.println(" amps");             // print calc. current value
  Serial.println("");
}

void reset(String &mem_map, float &f_vol, float &f_cur, String &vol, String &cur, uint8_t inputs[4], String bits[4]){
  memory_map = "";                              // reset memory map
  final_voltage = 0;                            // reset calculated voltage
  final_current = 0;                            // reset calcualted current
  voltage = "000000000000000";                  // reset voltage bits
  current = "000000000000000";                  // reset current bits
  for (int i = 0; i < 4; i++){                  // reset all input containers
    inputs[i] = 0;
    bits[i] = "";
  }
}

String toBinary(const uint8_t dec){
  int counter = 0;                              // tracks position of bitmask
  String temp = "00000000";                     // 8 bit container to hold binary result

  for(uint8_t i = 0x80; i != 0; i >>= 1){       // applies shifting bitmask and stores result to temp string
    temp[counter] = (dec & i) ? '1' : '0';      // if (dec & i) != 0, then temp[counter] = 1, else temp[counter] = 0
    counter++;                                  // increments position of bitmask tracker  
  }
  return temp;                                  // final result is 8-char string of literal binary representation of input decimal Ex: 23 --> 00010111
}

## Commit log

2019-01-21 Added block diagrams, black box diagram, and bill of materials
    [Bill of Materials.xlsx]
2019-03-07 Added Drive files
    [Assembly99.0002.ipn, Assembly99.0015.iam, Assembly99.iam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]
2019-03-08 add descriptio for voltage selector diode
2019-03-08 move readme for schematics
2019-03-09 added schematic readme
2019-03-09 added connector pictures
2019-03-09 Added main board pics
2019-03-09 Added Mk1.1 and Mk1.0
    [1-1721150-0.0001.ipt, 1-1721150-0.ipt, 1263695936.0002.iam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]
2019-03-09 Moved files
    [Transformer.STL, Transformer4Dummy.STEP, Transformer4Dummy.STL]
2019-03-13 Small fixes to V7
    [ESP_Firmware_V6_1.ino, ESP_Firmware_V7.ino]
2019-09-23 Add file for arduino ino
2019-10-14 add i2c scanner
